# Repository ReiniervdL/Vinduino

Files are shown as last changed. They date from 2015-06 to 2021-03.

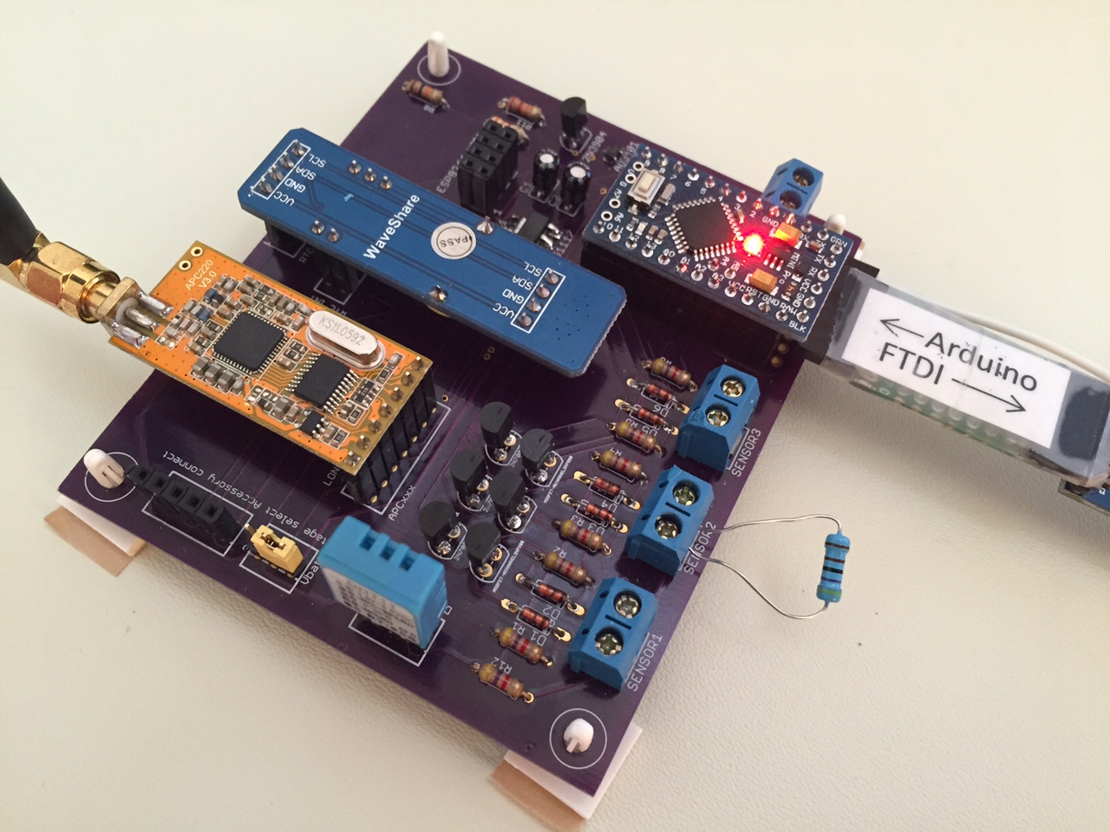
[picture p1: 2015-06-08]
Vinduino-R.JPG

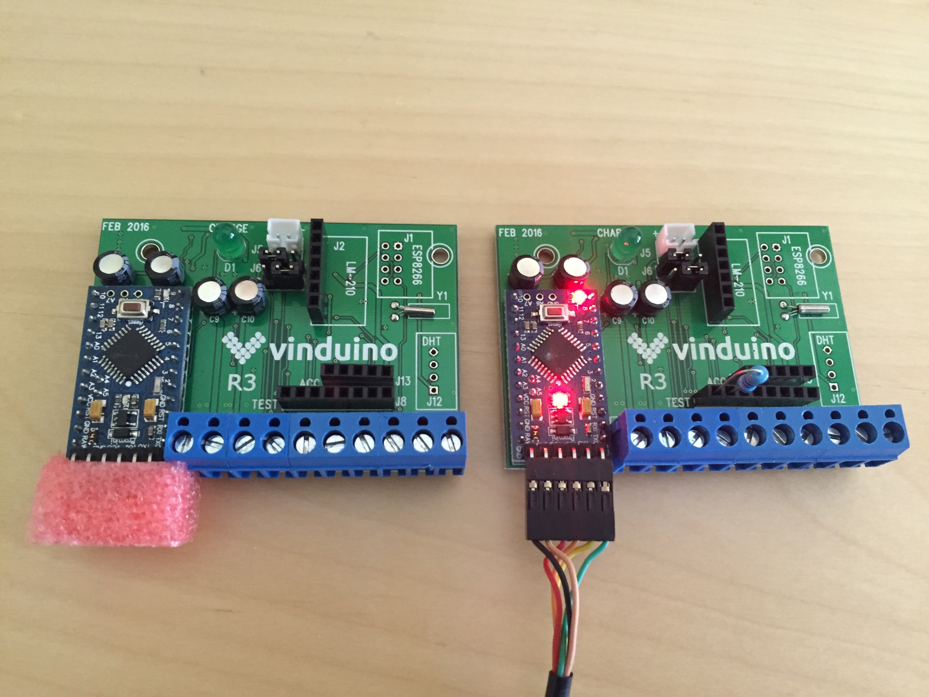
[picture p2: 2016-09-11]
Vinduino-R3/IMG_2257 2.JPG

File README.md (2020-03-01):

# Vinduino

The Vinduino project started from the necessity to manage irrigation in my small Southern California vineyard, by monitoring soil moisture at different depths and at several vineyard locations. 
Soil moisture monitoring systems have been around for decades, but they cost hundreds to thousands of dollars and -because these systems are proprietary- there will be ongoing cost to customize and maintain these systems. As a small vineyard owner, I needed something low cost and flexible.
The open source Arduino platform, together with low cost gypsum soil moisture and salinity sensors, provides all that. While I first envisioned the Vinduino project (Vineyard + Arduino) for my personal interest and needs, but now the scope has broadened to providing easy to use, open source, low cost solutions for agricultural irrigation management.

Saving water is more important now than ever. The four year drought in California made everybody realize the importance of reducing water use. But it is not just California that is plagued by prolonged drought periods. Large agricultural areas in South America, India, China, and Africa suffer from continuing water shortage as well.

The Vinduino project provided the following results, published on the Vinduino blog, Hackaday, and Github:

* DIY calibrated gypsum soil moisture sensors (Watermark SS200 is also supported)
* Hand held sensor reader (soil moisture, soil/water salinity, water pressure)
* Solar powered remote sensor platform (Vinduino R3), available on Tindie.com
	Options include:
	4 electrically separated inputs for soil moisture sensors
	Wifi (ESP8266), Globalsat LM-210 private LoRa network module, Globalsat LM-513 module for LoRaWAN (The Things Network)
	Irrigation valve control, optional pressure sensor for valve operation feedback
	several options for temperature/humidity sensors
	Built in solar battery charger
	Built in real time clock for precise irrigation timing
* Gateway to connect multiple LoRa end nodes to the Internet via Wifi (Vinduino Gateway)

All publicly released programming and documentation is available for free under the GNU General Public License 3.0.

For non-DIY we offer commercial products at www.vinduino.com and https://www.amazon.com/Vinduino-Agricultural-Irrigation-Monitoring-Starter/dp/B0828JCK49

Support web site: https://vinduino.freshdesk.com/support/home

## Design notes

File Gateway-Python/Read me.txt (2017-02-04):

The Vinduino gateway example code for the Globalsat LD20H USB dongle is written in Python3.

Python modules needed for the Vinduino gateway script:
- serial
- time
- thingspeak (linux install: $ sudo pip3 install thingspeak)
- sqlite3

DB browser for SQLite (http://sqlitebrowser.org) is a great program to manage the SQLite database.
Linux install: $ sudo apt-get install sqlitebrowser

For Windows, install the Cypress USB serial driver

For Linux: 
Linux does not require a special drivers for the USB serial interface, however ensure that you have qt4, gcc, and libusb installed.  The USB driver stack in Linux has a built-in driver for CDC-ACM class devices. The Cypress chip inside the LD-20 supports CDC-ACM class, CDC-ACM driver gets automatically bound to the device and creates a device node in /dev/ttyACM*(* -The name of device node will vary based on the number of devices connected).

Here is a good description for testing the USB serial connection in Linux:
http://www.cypress.com/knowledge-base-article/testing-usb-serial-bridge-controller-configured-usb-uart-linux-kba92551

I found that Ubuntu and RPI recognized the USB serial port, but likely assumed it was an AT-command modem. 

A solution that worked for me is to bypass the ModemManager: 

sudo systemctl mask ModemManager.service

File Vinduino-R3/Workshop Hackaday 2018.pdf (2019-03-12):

# Workshop

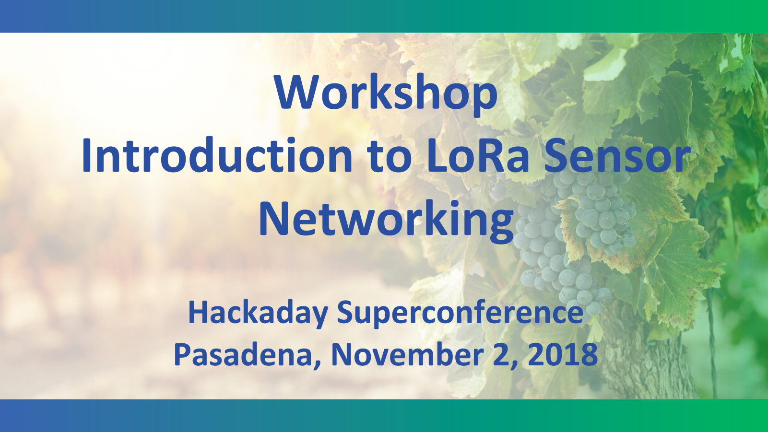
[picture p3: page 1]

# Introduction to LoRa Sensor Networking

# Hackaday Superconference Pasadena, November 2, 2018

# WHAT YOU WILL LEARN

## WHAT IS LORA, AND WHAT MAKES IT DIFFERENT

- Bandwidth, Range, Power
- Network provider: The Things Network

## Globalsat LM-110H1 LoRa module

- Manual setup with serial communication
- Useful AT commands
- Joining a local LoRa network
- Transmit data to an application
- Receive data from an application
- Visualize data in MyDevices Cayenne

# WHAT IS LORA?

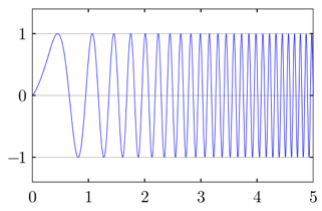
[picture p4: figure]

### Long range, low energy, wireless communication

- Typical 5 mile range with line-of sight
- Suitable for battery operated sensors
- Small data packets, 30 seconds/day air time
~ every 15 - 30 minutes
- Star network topology
- One gateway can support hundreds of stations

### Unlicenced Frequency bands

- USA 902 – 928 MHz, 64 channels
- Europe 863 – 870 MHz, 8 channels

### Modulation

- Chirp spread spectrum, 3 x greater distance than NB FSK
- Data rate depends on bandwidth and spreading factor

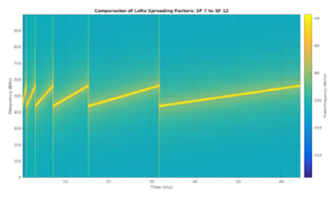
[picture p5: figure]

Sakshama Ghoslya

# LORA NETWORK ARCHITECTURE

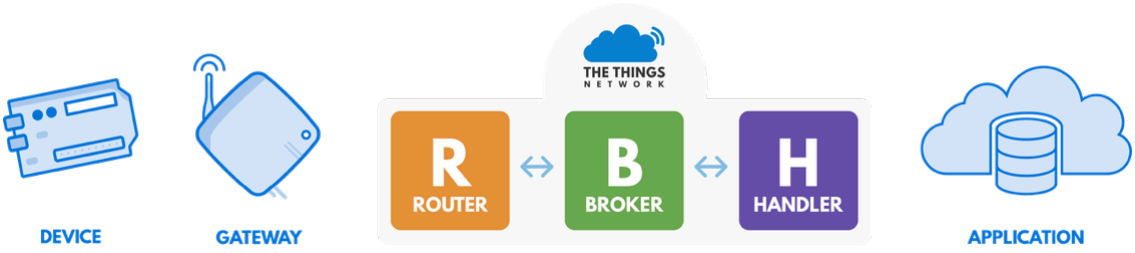
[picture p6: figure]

# LORA NETWORK IN TEMECULA

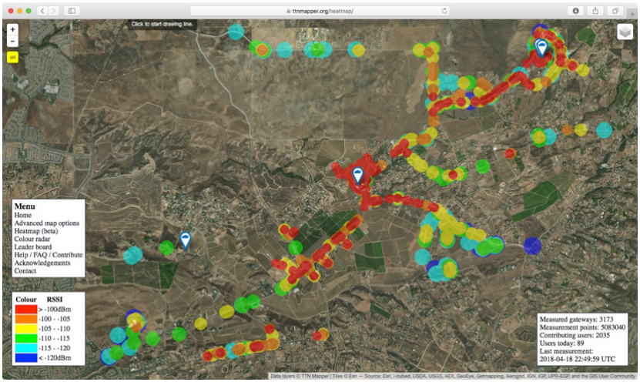
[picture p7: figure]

ttnmapper.org

# WORKSHOP PLAYGROUND

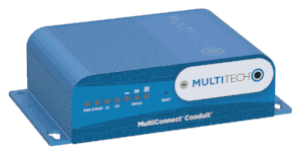
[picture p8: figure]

### LORAWAN GATEWAY

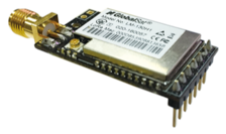
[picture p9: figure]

- MuLtitech Conduit
- Set up for TheThingsNetwork

### LORA NETWORK PROVIDER: TTN

- Free to use LoRaWAN networking
- Community owns and deploys the network
- 5,000 communities worldwide

### YOUR WORKSHOP KIT

- Globalsat LM-110H1 LoRa radio module
- NL100 USB-2-Serial adapter
- 915 MHz Antenna

# GLOBALSAT LM-110H1

LM-110H1 Pin Definition
Pin | Signal Name | I/O | Description
1 | GND | - | Ground
2 | VCC | - | 3.0 – 6.0V
3 | RXD | Input | 3.3V UART input
4 | TXD | Output | 3.3V UART output
5 -7 | - | - | -

Hardware Specifications
Chipset | SEMTECH LoRa SX1276
LoRaWAN Class | Class A device, Receives after Tx
Frequency | 862-870MHz (Model: LM-110E) 902-928MHz (Model: LM-110H)
Transmission Power | 100mW (max.)
UART | Baud Rate : 57600bps Parity: 8N1
Operation Voltage | 3.0V~6V
Current Consumption | Receiving: 21 mA (typical) Transmitting: 125 mA (typical) Sleeping: 5 uA (typical)
Transmission Distance | 1KM~10KM (0.81Kbps)
Receiving Sensitivity | -132dBm@0.81Kbps

# BEFORE WE GET STARTED

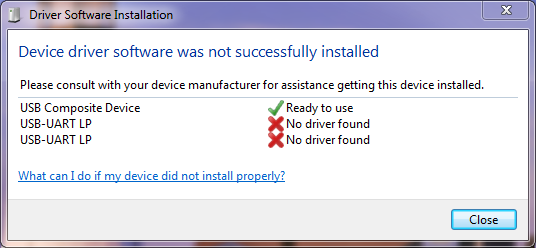
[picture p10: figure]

## WIFI - SSID: | - Pass: |

## WINDOWS USERS

- Install Cypress USB serial driver

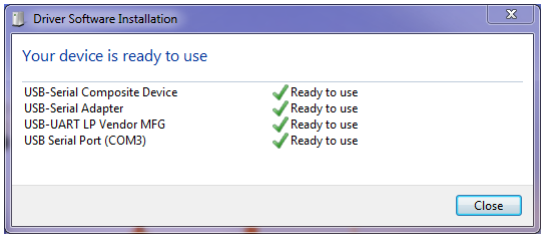
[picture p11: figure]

## Everybody

- Install CoolTerm serial communications program http://freeware.the-meiers.org
- Set up user account at thethingsnetwork.org
- Set up user account at mydevices.com

# BEFORE WE GET STARTED-2

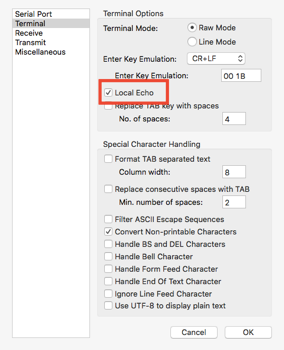
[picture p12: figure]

## CoolTerm Settings

- Select correct serial port
- Baudrate:
57600, 8 bits, no parity, 1 stop bit
- Terminal: Local Echo

## The Things Network

- Set up a user account

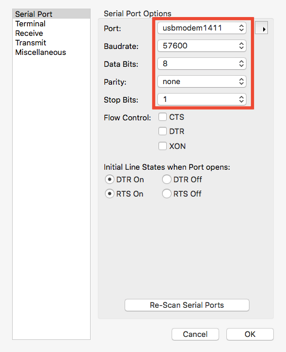
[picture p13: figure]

- https://account.thethingsnetwork.org/register

# AT COMMANDS QUICK REFERENCE

Command | Description | Response
AAT1 Reset | Reboot the LM-110H1 | OK
AAT1 Save | Save parameters to flash | OK
AAT1 SLEEP | Enter sleep mode | OK
AAT2 JoinMode=1 | OTAA activation mode | OK
AAT2 DevEui=? | Device LoRa Mac address | 8-byte hex number
AAT2 AppEui= (enter hex here) | Application identifier | OK
AAT2 AppKey= (enter hex here) | Encryption key | OK
AAT2 Tx=2,uncnf,AABBCC (hex payload) | Send data | OK Tx_ok Tx_noACK Tx_no_free_ch Tx_not_joined Rx …

# MODULE MANUAL CONFIGURATION

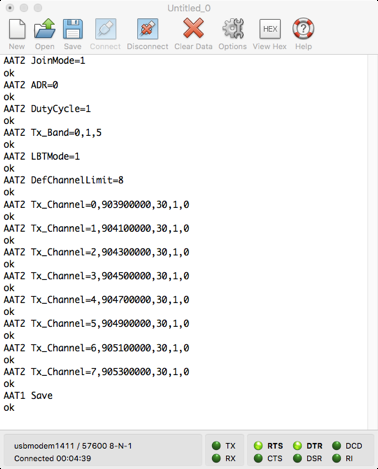
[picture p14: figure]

AAT2 JoinMode=1
AAT2 ADR=0
AAT2 DutyCycle=1
AAT2 Tx_Band=0,1,5
AAT2 LBTMode=1
AAT2 DefChannelLimit=8

AAT2 Tx_Channel=0,903900000,30,1,0 AAT2 Tx_Channel=1,904100000,30,1,0 AAT2 Tx_Channel=2,904300000,30,1,0 AAT2 Tx_Channel=3,904500000,30,1,0 AAT2 Tx_Channel=4,904700000,30,1,0 AAT2 Tx_Channel=5,904900000,30,1,0 AAT2 Tx_Channel=6,905100000,30,1,0 AAT2 Tx_Channel=7,905300000,30,1,0 AAT1 Save

Same for every
module setup

Frequencies can differ
per network provider

# TTN ADD APPLICATION

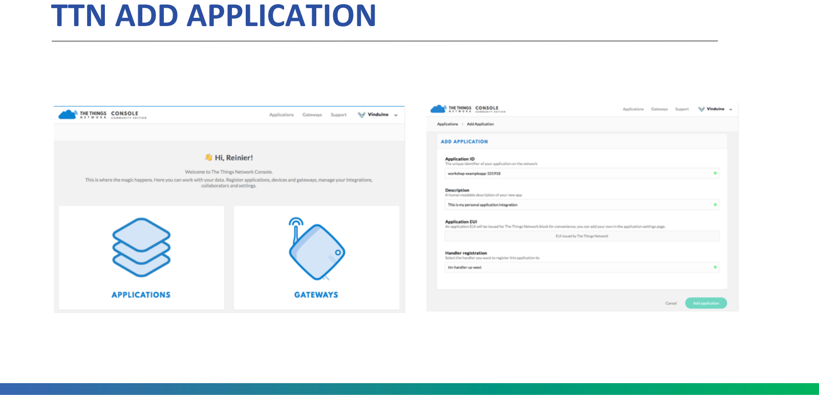
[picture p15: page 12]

# MODULE MANUAL CONFIGURATION-2

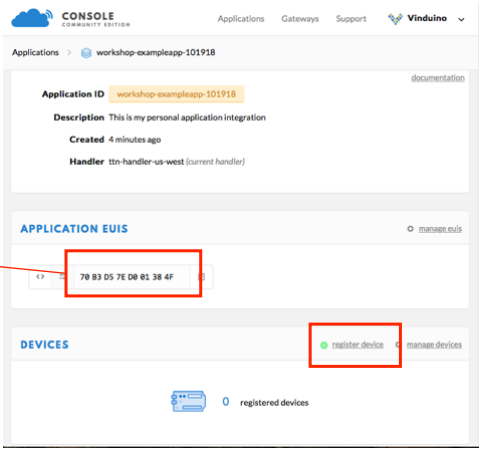
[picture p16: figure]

AAT2 DevEui=?
000DB53908643681
(should be the same as module marking)

AAT2 AppEui=70B3D57ED001384F AAT1 Save

AAT2 AppKey=
AAT1 Save
AAT1 Reset

Save DevEUI for
TTN registration

# TTN REGISTER DEVICE

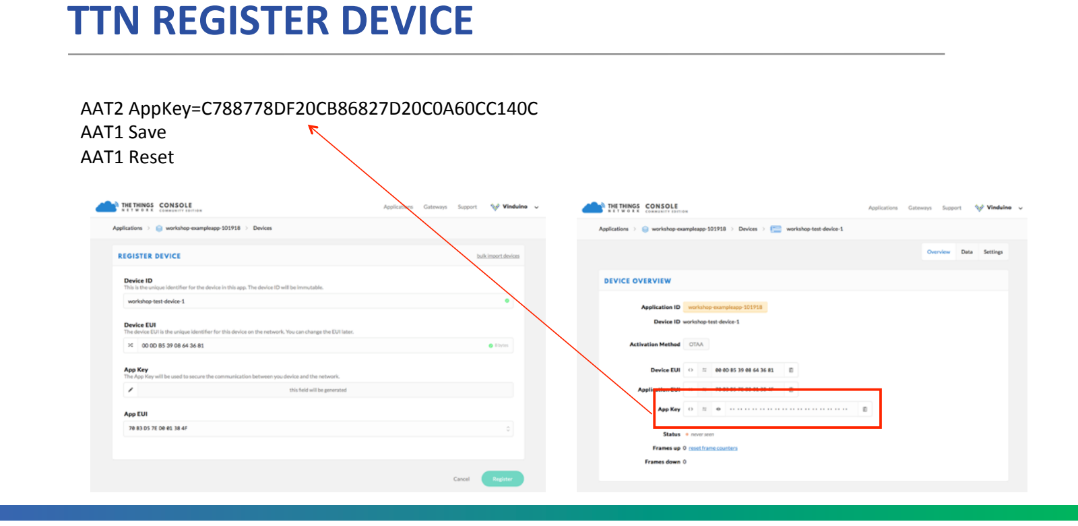
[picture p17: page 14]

AAT2 AppKey=C788778DF20CB86827D20C0A60CC140C AAT1 Save
AAT1 Reset

# CONNECTED TO THE LORA NETWORK!!

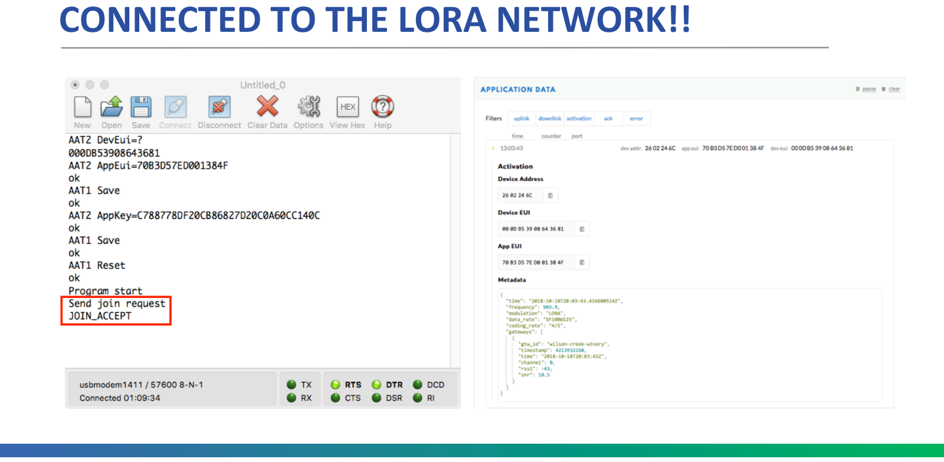
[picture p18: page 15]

# NOW LET’S SEND SOME DATA!!

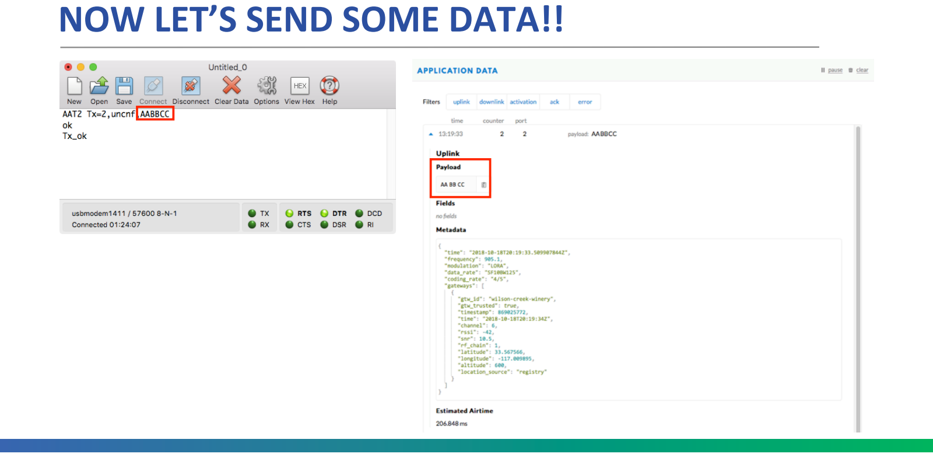
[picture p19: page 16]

# RECEIVING DATA

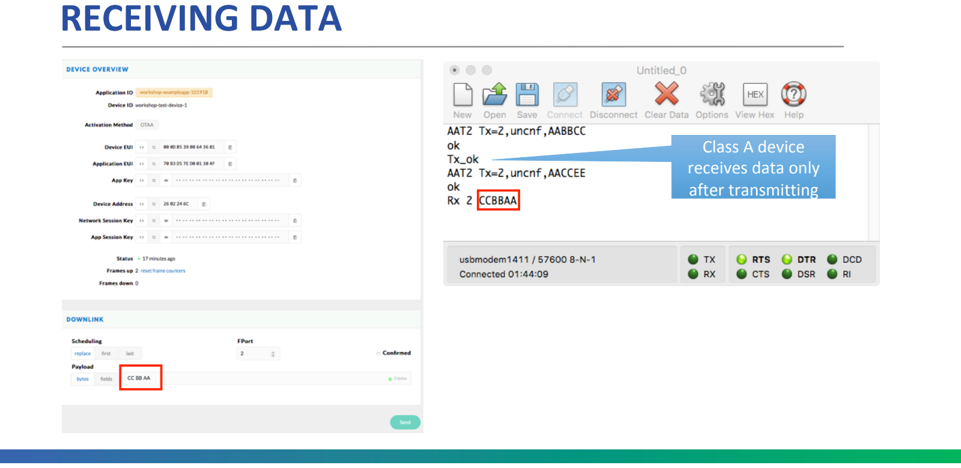
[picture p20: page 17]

Class A device
receives data only
after transmitting

# VISUALIZE YOUR SENSOR DATA

## ADD CAYENNE INTEGRATION

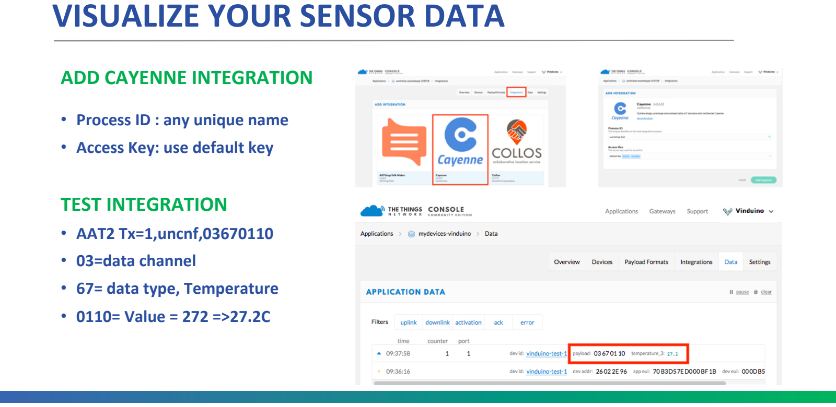
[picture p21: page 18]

- Process ID : any unique name
- Access Key: use default key

## TEST INTEGRATION

- AAT2 Tx=1,uncnf,03670110
- 03=data channel
- 67= data type, Temperature
- 0110= Value = 272 =>27.2C

# USING CAYENNE

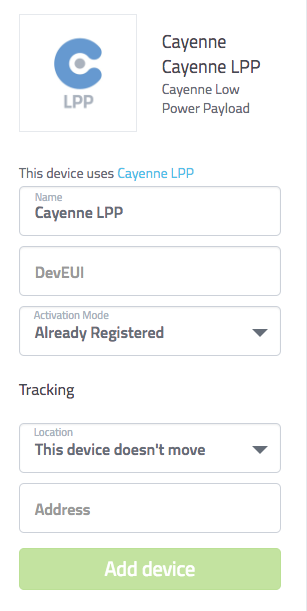
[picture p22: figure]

## SET UP DEVICE IN CAYENNE

- Add new … Devices & Widgets
- Select LoRa / TheThingsNetwork
- In devices list: select Cayenne LPP
- Enter DevEUI:
- AAT2 Tx=1,uncnf,03670110

# CONGRATULATIONS

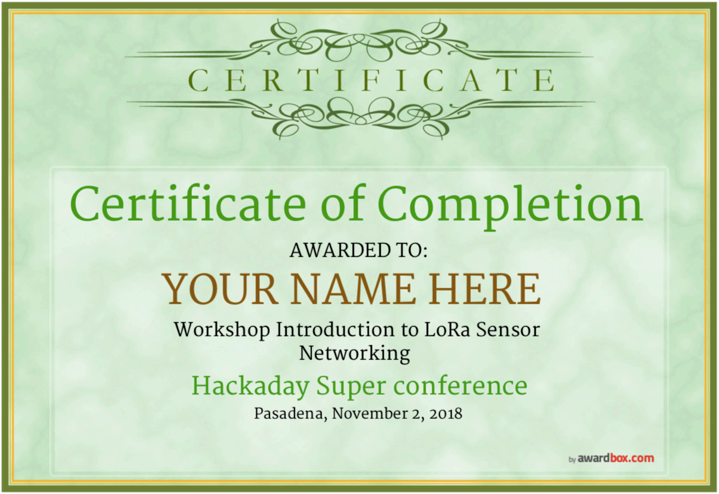
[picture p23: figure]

# USEFUL LINKS

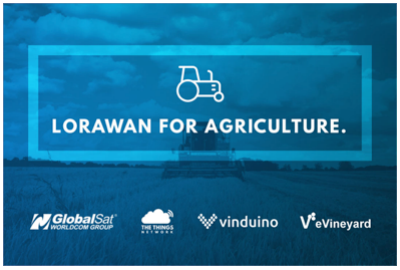
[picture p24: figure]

www.thethingsnetwork.org/community/losangeles/ https://www.thethingsnetwork.org www.usglobalsat.com
www.vinduino.com
www.tindie.com
lora-alliance.org

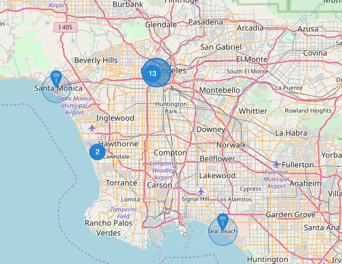
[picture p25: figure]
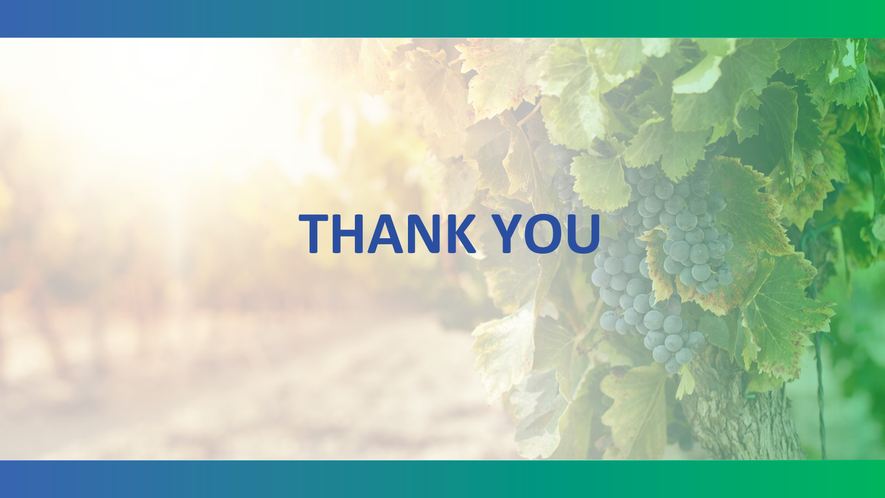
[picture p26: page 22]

# THANK YOU

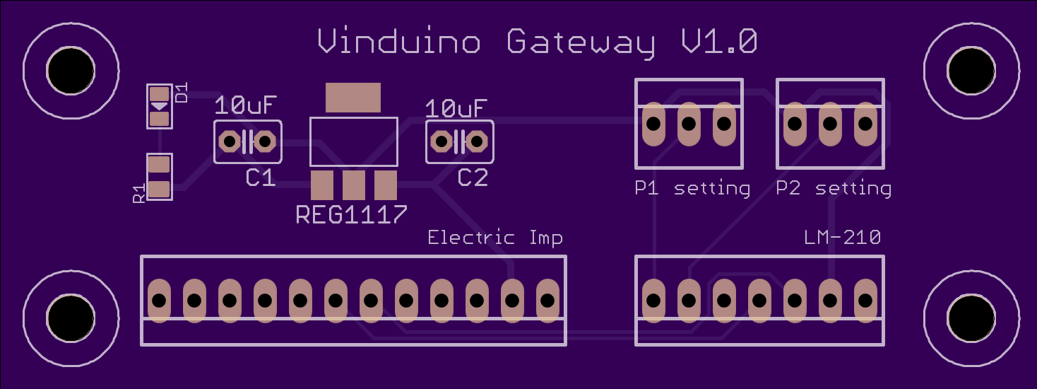
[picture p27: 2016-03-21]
Vinduino-Imp-GW-PCB/Vinduino-GW.png

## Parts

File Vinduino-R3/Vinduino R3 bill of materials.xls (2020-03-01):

Part/Designator | Manufacture Part Number | Quantity | Hole Pads | Ext hole pads | Ext SMD pads | Description | Comments
U4 | 74HC4052D,653 | 1 | 16 |  | 16 | IC MUX/DEMUX DUAL 4X1 16SOIC
R14, R15, R8 | RC0805FR-07100KL | 3 | 2 |  | 6 | RES SMD 100K OHM 1% 1/8W 0805
R9, R10 | RR1220P-4751-D-M | 2 | 2 |  | 4 | RES SMD 4.75KOHM 0.5% 1/10W 0805
R1, R2,R3, R6, R7, | RMCF0805JT4K70 | 5 | 2 |  | 10 | RES SMD 4.7K OHM 5% 1/8W 0805
R5 | RC0805JR-0710KL | 1 | 2 |  | 2 | RES SMD 10K OHM 5% 1/8W 0805
C1, C4, C5, C6, C7, C8 | CC0805ZRY5V9BB104 | 6 | 2 | 12 |  | CAP CER 0.1UF 50V Y5V 0805
F1 | RXEF025-2 | 1 | 2 | 2 |  | POLYSWITCH RXE SERIES 0.25A | SMD type preferred
C2 | C0603C100J5GACTU | 1 | 2 |  | 2 | CAP CER 10PF 50V NP0 0603
U3 | PCF8563T/5,518 | 1 | 8 |  | 8 | IC RTC CLK/CALENDAR I2C 8-SOIC
Y1 | ECS-.327-8-14X | 1 | 2 | 2 |  | CRYSTAL 32.7680KHZ 8PF T/H
J4 | OSTTA020161 | 5 | 2 | 10 |  | TERMINAL BLOCK 5MM VERT 10 POS PCB | use 5x 2 terminal or 1 x 10 pos terminal block
U2 | MCP73831T-2ACI/OT | 1 | 5 |  | 5 | IC CONTROLLR LI-ION 4.2V SOT23-5
D1 | LTST-C171GKT | 1 | 2 | 2 |  | LED GREEN CLEAR 0805 SMD | or through hole LED
R4 | RC0805JR-07470RL | 1 | 2 |  | 2 | RES SMD 470 OHM 5% 1/8W 0805
J13 | PPTC051LFBN-RC | 1 | 5 | 5 |  | CONN HEADER FEM 5POS .1" SGL TIN
J2 | PPPC071LFBN-RC | 1 | 7 | 7 |  | CONN HEADER FEMALE 7POS .1" GOLD
J3, J6 | 68000-103HLF | 2 | 3 | 6 |  | BERGSTIK II .100" SR STRAIGHT
J3, J6 | 969102-0000-DA | 2 |  |  | 0 | SHUNT JUMPER .1" BLACK GOLD
U6 | MCP1825S-3302E/DB | 1 | 4 |  | 4 | IC REG LDO 3.3V 0.5A SOT223-3
U5 | SI1869DH-T1-E3 | 1 | 6 |  | 6 | IC LOAD SW LVL SHIFT 20V SC70-6
D2, D3, D4, D5 | MMBZ9V1ALT1G | 4 | 3 |  | 12 | Dual TVS protection diode
C9, C10, C11, C12 | ECE-A1AKS470 | 4 | 2 | 8 |  | CAP Alum 47UF 20% 10V Radial | value not critical
J5 | B2B-PH-K-S(LF)(SN) | 1 | 2 | 2 |  | JST-PH 2-Pin SMT 2 Positions Header, Shrouded Connector 0.079" (2.00mm) | non-angle connector (vertical insertion) preferred
Arduino Pro Mini 3.3V 8MHz |  | 1 | 58 | 58

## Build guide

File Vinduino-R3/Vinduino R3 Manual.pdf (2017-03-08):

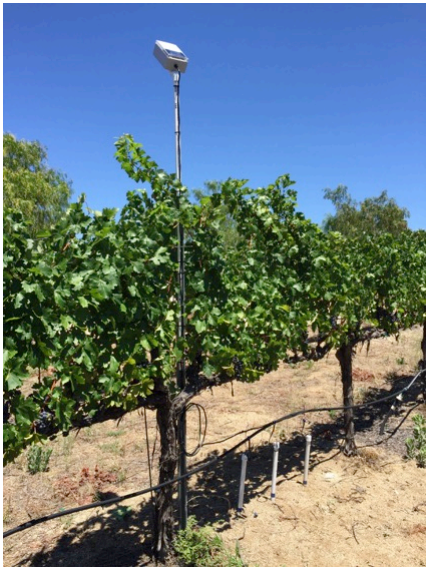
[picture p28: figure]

## Vinduino User Manual

Draft version July 30,2016 Updated August 4, 2016

Table of contents

## Introduction

Vinduino remote sensor platform for optimizing agricultural irrigation

The Vinduino R3 sensor station contains all the electronics needed for a solar powered remote sensor platform. It is designed for optimizing agricultural irrigation, aimed at saving 25% irrigation water. This board represents the 3rd generation design of our remote sensor platform, and has gone through extensive vineyard field trials.

Features:
- Arduino based, easy to customize programming
- 4 electrically separated inputs for soil moisture sensors
- Supports Wifi (ESP8266, not included) or Globalsat LM-210 LoRa module for long range
- Irrigation valve control output
- Several options for temperature/humidity sensors
- Solar battery charger
- Real time clock for sleep mode power saving and precise irrigation timing
- Load switch for actuators or sensors that require electric power

Supported sensors:
- Vinduino soil moisture sensor
- Watermark SS200 soil moisture sensor
- DHT11, DHT22
- DS18b20

The Vinduino board is designed for continuous unattended operation. It can be powered by a small solar panel, and the battery charger maintains a Li-ion battery fully charged, to keep the system working during the night and during periods with dense cloud cover. The battery voltage can be monitored remotely to check battery health.

The LM-210 module requires a compatible gateway, and is designed for LoRa LAN.

## Scope

This user manual covers use and installation of the Vinduino R3 remote sensor station and the Vinduino Gateway

## Disclaimer

Always use multiple data sources, appearance of your crop, and common sense when making irrigation decisions. Vinduino LLC is not responsible for crop yield results.

## Sensors

The Vinduino R3 is designed to support up to 4 resistive soil moisture sensors. These can be gypsum sensors, like the Vinduino sensor shown below, or commercial sensors like the Watermark SS200 granular matrix sensor.

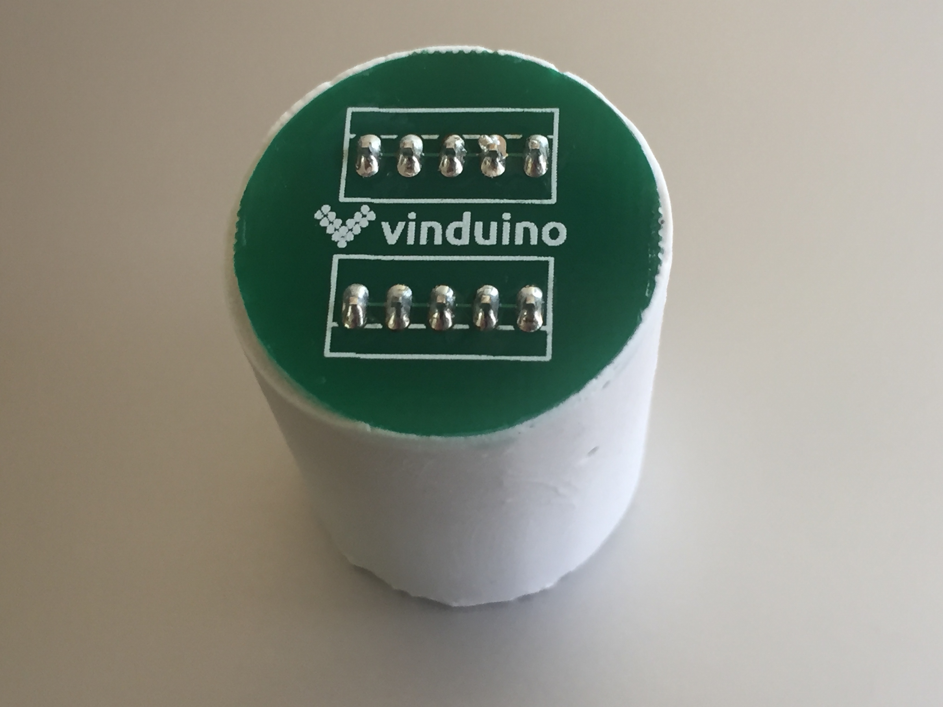
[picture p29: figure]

The Vinduino design uses short alternating electrical pulses to measure the resistance of the sensor, which is a measure of the water content of the soil. A low resistance indicates high moisture, whereas a high resistance value indicates low water availability. The resistance is expressed in Ohm, and can be used in combination with a calibration chart to determine water content.

Vinduino calibration chart to be inserted here at next document update

For Watermark SS200 sensors, calibration is well documented (Shock et all) and available on-line:
http://www.kimberly.uidaho.edu/water/swm/Calibration_Watermark2.htm

The Vinduino remote sensor station has the option to support other types of sensors. Here is a list of sensors that have been tested to work with the Vinduino:

DHT11 air temperature and humidity sensor, temperature accuracy 2%, RH accuracy 5%

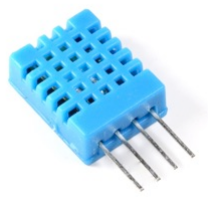
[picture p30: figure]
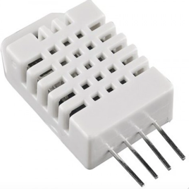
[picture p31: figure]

DHT22 air temperature and relative air humidity sensor temperature accuracy 0.5%, RH accuracy 2%

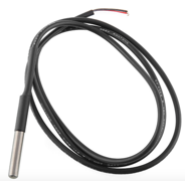
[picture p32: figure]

DS18b20 waterproof 0.5% accurate digital temperature sensor 3 wire interface (Red =Vcc, Black =ground, Yellow=data out)

The choice of sensors needs to be agreed when ordering, as the Vinduino R3 programming and Internet interface needs to be configured to support the selected sensors. Sensors can be added later, and the supporting software can be upgraded in the field.

Sensor installation
The installation of sensors needs preferably be done at least two weeks before the anticipated activation of the remote sensor station.
The Vinduino project uses 4 soil moisture sensors at different depths per location to determine the percolation of irrigation water in the soil.
For wine grapes, the recommended installation depths are 1 foot, 2 feet, 4 feet, and 5 feet.
The sensor at 5 feet is to be considered below the active root zone, and should show low moisture levels as drainage of irrigation water below 4 feet is out of reach of the grapes.

Ideally, all sensors should be vertically aligned close to an irrigation dripper.
For easy maintenance and replacement, 1“ PVC pipe is recommended to mount and install the sensor at the desired depth. Keeping 1’ of pipe above ground helps avoid wildlife damage to the electrical wiring.

TIP:
For Vinduino sensors, PVC pipe can be widened after applying hot air with a heat gun. After inserting the sensor, re-heating with shrink the pipe to tightly fit around the sensor.

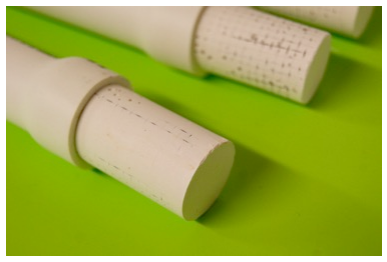
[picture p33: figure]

Gypsum sensors need a good soak before installation in the soil. To ensure good soil contact, put some soil slurry in the hole and make sure that the sensor is well settled into the slurry before filling up with soil.
Link to sensor installation guidelines: http://mea.com.au/upload/new/product_brochures/b83_soil-moisture_sensor_installation_guide_web.pdf

## Vinduino R3, remote sensor station

Solar power
The remote sensor station is designed for continuous unattended operation. It is powered by a small solar panel, and the battery charger keeps the battery fully charged to keep the system working during the night and during periods with dense cloud cover. A green LED on the electronics board indicates that the charger is operational.
The battery voltage is measured and sent together with the sensor data. A healthy battery should provide a voltage between 4.2V and 3.6V. Below 3.6V, the battery is close to empty.

The battery connector is also used to switch the system on or off. Disconnect the solar panel before disconnecting the battery to avoid the system continuing on solar power.

Important: the solar panel is connected to the wire terminal block. The red wire connects to the “+”, and the black wire connects to the “-“. Connecting the solar panel with the wires with reversed polarity will damage the battery charging chip.

Connecting sensors
The Vinduino R3 has inputs for 4 soil sensors. The soil sensor wires connect to the wire connection block. Sensor 1 wires are connected on the right side. The type of wiring is not critical for the accuracy or performance of the soil moisture measurement.

The printed circuit board is designed to support a DHT11 or DHT22 sensor (temperature and relative humidity). These sensors are not waterproof and can only be used for measuring inside the enclosure.
For temperature measurement outside the enclosure, soil or air temperature, a waterproof temperature sensor like the DS18b20 can be used.

Other sensors can be attached using the “Accessories” connector on the electronics board. This connector gives access to 2 digital pins, an analog input, and a switched 3.3V power supply pin that can be used for sensors that require electric power. Future use of the accessories connector is to control an irrigation valve and water pressure sensor.

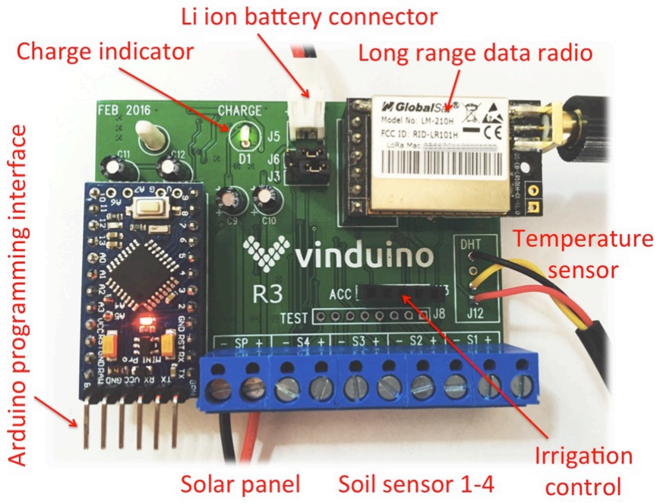
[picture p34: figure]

Timer
The Vinduino R3 has an integrated clock chip that is used to wake up the system from power saving sleep mode. After the Vinduino is done with making measurements and transmitted the measurement data, it goes back to sleep again.
During the active mode, a LED on the Arduino board lights up.
Typically, the timer is programmed for 15 minutes or one hour. When many remote sensor stations share one gateway, it is better to have longer interval times to avoid “crowding” of the radio frequency.

The timer can also be used (future) for precision irrigation timing, or keeping system time.

LM-210 radio module
The telemetry radio unit used in the Vinduino project follows the recent LoRa standard, which allows long range wireless networking. The unit is FCC approved in the USA for license-free use in the 915 MHz band.
Range is dependent on the conditions. With the supplied antennas typically 1-3 miles is possible. With line-of-sight and external antennas, considerable longer distances are possible.

The unit can be re-programmed for different output power levels and frequency. The default settings are 915 MHz and 100mW power. Frequency change is only needed in vase of strong local interference from other users of the frequency or in case of installation in Europe where 868MHz is used for LoRa.

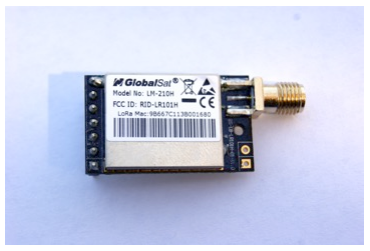
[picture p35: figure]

The Vinduino sensor station is designed for supporting the LM-210. Before programming the Arduino microcontroller board with a USB adapter cable, the LM-210 module should be removed to avoid USB level voltages (5V) reaching the module.

Programming
In order to change the program code of the Vinduino, for instance to change the wake up time or change sensors, you will need a programming cable and Arduino PC software. The USB programming cable is needed to connect to a PC
Please use the 3.3V version of the cable: http://amzn.com/B00DJBPIGI

The radio module needs to be removed before programming and connecting the programming cable.

Arduino programming software is available for free for most recent computer operating systems: https://www.arduino.cc/en/Main/Software

Vinduino programming code is available for download via Github: https://github.com/ReiniervdL/Vinduino

Vinduino R3 installation and maintenance
The remote sensor station comes as a watertight NEMA enclosure. Sensor cables should enter the enclosure using a NEMA rated cable gland (supplied).
The unit can be mounted at an angle for the solar panel to get best exposure to the available sunlight. Best direction for the solar panel is facing South.

TIP: It is recommended to spray paint the transparent cover partially white to keep the temperature inside the enclosure lower. Leave the solar panel area clear.
This will improve the life of your battery.

Due to exposure to sunlight, the battery will be operating at high operating temperatures. It is therefore recommended to frequently check the battery for visible mechanical deformation, in which case replacement is needed. Annual replacement of the battery is recommended preventive maintenance for outdoors installations where the unit is in continuous operation.

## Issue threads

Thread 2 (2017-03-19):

LowPower.h source

Elwell, 2017-03-19:
Hi Reinier,

In the arduino sketches, you #include "LowPower.h" that isn't in the tree.

Is this from https://github.com/rocketscream/Low-Power, described in http://www.rocketscream.com/blog/2011/07/04/lightweight-low-power-arduino-library/ ?

ReiniervdL, 2017-03-19:
Hi Andy,
Correct, Vinduino uses the rocketscream low power library

Closed 2017-03-19.

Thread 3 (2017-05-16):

Negative values of resistance, Soil moisture always zero!

aniket5941, 2017-05-16:
I'm using Vinduino-H_V3.1 code, soil moisture always shows **zero** for **WET** and **DRY** and resistance is always **NEGATIVE** I done connection according picture attached, but I'm using **4700 ohm resistance** help me what I'm doing wrong, I have attached images of connection and readings, first reading image is of wet and second is for dry.
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

ReiniervdL, 2017-05-16:
The code for the handheld was written for Arduino Pro Mini pin assignments.
What model of Arduino are you using?

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

aniket5941, 2017-05-17:
Arduino pro mini 3.3v model

ReiniervdL, 2017-05-17:
First question, do you have test equipment: multimeter, oscilloscope?

The code was written for the 5V version of the Arduino pro mini.
For 3.3V, I recommend removing the diodes, as they take away 0.6V from the voltage divider supply.
Next you need to program the outputs to high impedance when not used as output.
You can copy the code from the Vinduino R3 on Github for this.

Last but not least, double check your wiring.

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

aniket5941, 2017-05-18:
No I'm not using any test equipment: multimeter, oscilloscope.
I tried Vinduino R3 on **Arduino UNO** but the same problem occurs.

ReiniervdL, 2017-05-22:
I'd like to help with debugging if you provide me basic measurement data.  A $10 digital multimeter will go a long way get getting insight in what's going on. If you want to skip fault finding,  use the PCB design for the handheld reader, available here:
https://oshpark.com/shared_projects/QWzdU5S6

aniket5941, 2017-05-23:
Thank you very much ,
I have DMM and my is circuit on bread board, I'm in little hurry so pcb would take time, so how should I proceed what data would you like to have from me.

ReiniervdL, 2017-05-23:
Can you first check the power supply voltage?
Next, can you modify the “Blink” example program (in the Arduino IDE) to check that the two outputs driving the diodes are toggling.
Make the delay long, so your DMM can track the changing states.

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

warriorfenixSM, 2018-05-14:
This values is with 22k in WM1:

WM1: 298552,2
WM1: 8670,15
WM1: 201160,2
WM1: 8706,15
WM1: 297079,2
WM1: 8409,15
WM1: 284256,2
WM1: 7925,15
WM1: 291596,2
WM1: 8521,15
WM1: 322377,2
WM1: 7823,15
WM1: 183822,2

Closed 2020-03-01.

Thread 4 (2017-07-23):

USB serial crash using ftdi

pandrews255, 2017-07-23:
I'm using the Vinduino R3 with the 2nd LM-210 wired into the Raspberry Pi.  After a random amount of time (minutes but rairly to hours) the USB serial crashes out and forces a reboot/re-plug of the usb ftdi in order to work again.  Easiest way to see this error is through:

`dmesg -T`
with the result:
`Nov 4 14:23:13 localhost kernel: [11761.350820] ftdi_sio ttyUSB0: usb_serial_generic_read_bulk_callback - urb stopped: -32 `
(Note: this was not my exact error, but was close enough and how I found my solution.)

Solution:[https://github.com/raspberrypi/linux/issues/1187](url)

> You could try the nuclear option - add dwc_otg.speed=1 to /boot/cmdline.txt - this forces the entire bus to USB1.1 speeds. If you still get disconnects after that, then it's probably safe to say that the Pi isn't the issue.

This fixed my issue, though it seems a bit inelegant.  I don't need any high speed USB devices on the pi, so it seems effective.

No real question here, just posting for posterity.  Perhaps best in a Wiki format, but didn't see any other wiki pages.  If a more elegant solution exists, I'd be willing to try it.

ReiniervdL, 2017-07-25:
Thanks!!
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

Closed 2017-08-06.

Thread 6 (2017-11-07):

Bill of Materials for Vinduino R3

Bigben83, 2017-11-07:
I cant seem to see a BOM list for the parts used on the R3
can you point me in the right direction please :-)

Bigben83, 2017-11-07:
I have done a list up from the Schematic, there is a few holes to fill though.
https://docs.google.com/spreadsheets/d/1UatllHvDW_FJPWLYLjqeTI9wG5EkYtphUCcHgDXFkBM/edit?usp=sharing

Bigben83, 2018-12-10:
Hello @ReiniervdL can you please tell me what the Diodes are D2-D5  are they a "9A1" 9.1V 0.3W zener?

DanChippps, 2020-02-27:
Hi @Bigben83, Did you manage to figure this question out?

Bigben83, 2020-03-01:
Hi @DanChippps no I didn't, I gather this is no longer maintained opensource hardware/software.
I have built several of these units. I will have a look and see what I actually used.

ReiniervdL, 2020-03-01:
The BOM has been added

Closed 2020-03-01.

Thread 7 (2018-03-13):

Soil Moisutre Measure not works!

warriorfenixSM, 2018-03-13:
Hi, i try works your source code: Vinduino-H_V3.1.ino with only one watermark connect to Arduino M0. But it doesn't work. I see the signal in the oscilloscope, but the code no changes values

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

And this mi code:

#include <math.h>

#define NUM_READS 11    // Number of sensor reads for filtering

typedef struct {        // Structure to be used in percentage and resistance values matrix to be filtered (have to be in pairs)
  int moisture;
  long resistance;
  double tension;
} values;

const long knownResistor = 4700;  // Constant value of known resistor in Ohms

int activeDigitalPin = 11;         // 6 or 7 interchangeably
int supplyVoltageAnalogPin;       // 6-ON: A0, 7-ON: A1
int sensorVoltageAnalogPin;       // 6-ON: A1, 7-ON: A0

int supplyVoltage;                // Measured supply voltage
int sensorVoltage;                // Measured sensor voltage

values valueOf[NUM_READS];        // Calculated moisture percentages and resistances to be sorted and filtered

int i;                            // Simple index variable

void setup() {
  // initialize serial communications at 9600 bps:

  SerialUSB.begin(9600);
analogReadResolution(12);
  // initialize the digital pin as an output.
  // Pin 6 is sense resistor voltage supply 1
  pinMode(11, OUTPUT);

  // initialize the digital pin as an output.
  // Pin 7 is sense resistor voltage supply 2
  pinMode(13, OUTPUT);
}

void loop() {

      bemoticCore.ON_SENS();
  for (i=0; i<NUM_READS; i++) {

    setupCurrentPath();      // Prepare the digital and analog pin values

    // Read 1 pair of voltage values
    digitalWrite(activeDigitalPin, HIGH);                 // set the voltage supply on
    delay(10);
    supplyVoltage = analogRead(supplyVoltageAnalogPin);   // read the supply voltage
    SerialUSB.print("SV:");
    SerialUSB.println(supplyVoltage);
    sensorVoltage = analogRead(sensorVoltageAnalogPin);   // read the sensor voltage
    SerialUSB.print("SV:");
    SerialUSB.println(sensorVoltage);
    digitalWrite(activeDigitalPin, LOW);                  // set the voltage supply off
    delay(10);

    // Calculate resistance and moisture percentage without overshooting 100
    // the 0.5 add-term is used to round to the nearest integer
    // Tip: no need to transform 0-1023 voltage value to 0-5 range, due to following fraction
    valueOf[i].resistance = long( float(knownResistor) * ( supplyVoltage - sensorVoltage ) / sensorVoltage + 0.5 );
    valueOf[i].moisture = min( int( pow( valueOf[i].resistance/31.65 , 1.0/-1.695 ) * 400 + 0.5 ) , 100 );
//    valueOf[i].tension = round( -20 * (double(valueOf[i].resistance)/1000) * ( 1 - 0.55)); // Watermark 0 < 1 kOhm
    valueOf[i].tension = round( ( -3.213 * (double(valueOf[i].resistance)/1000) - 4.093) / ( 1 - 0.009733 * (double(valueOf[i].resistance)/1000) - 0.01205*24)); // Watermark 1 < 8 kOhm
//    valueOf[i].tension = round(-2.246 - (5.239 * (double(valueOf[i].resistance)/1000)) - 0.06756 * pow(valueOf[i].resistance/1000,2)); // Watermark > 8 kOhm
//  valueOf[i].moisture = min( int( pow( valueOf[i].resistance/331.55 , 1.0/-1.695 ) * 100 + 0.5 ) , 100 );

  }
      sortMoistures();
 
      // Print out median values
      SerialUSB.print("SV: ");
      SerialUSB.println(supplyVoltage);
      SerialUSB.print("Se: ");
      SerialUSB.println(sensorVoltage);
      SerialUSB.print("Resistencia Sensor: ");
      SerialUSB.println(valueOf[NUM_READS/2].resistance);
      SerialUSB.print("Moisture Sensor: ");
      SerialUSB.println(valueOf[NUM_READS/2].moisture);
      SerialUSB.print("Tension Sensor: ");
      SerialUSB.print(valueOf[NUM_READS/2].tension);
      SerialUSB.println(" kPa");
      delay(3000);

}

void setupCurrentPath() {
  if ( activeDigitalPin == 11 ) {
    activeDigitalPin = 13;
    supplyVoltageAnalogPin = A2;
    sensorVoltageAnalogPin = A0;
  }
  else {
    activeDigitalPin = 11;
    supplyVoltageAnalogPin = A0;
    sensorVoltageAnalogPin = A2;
  }
}

// Selection sort algorithm
void sortMoistures() {
  int j;
  values temp;
  for(i=0; i<NUM_READS-1; i++)
    for(j=i+1; j<NUM_READS; j++)
      if ( valueOf[i].moisture > valueOf[j].moisture ) {
        temp = valueOf[i];
        valueOf[i] = valueOf[j];
        valueOf[j] = temp;
      }
}

ReiniervdL, 2018-03-13:
The Vinduino-H code is for a handheld reader, works for one sensor only.

Can you describe your setup?
Are you using the Vinduino handheld PCB?
Does the code compile?

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

warriorfenixSM, 2018-03-13:
I try to use the Vinduino handheld PCB and i have connect only sensors. I try use your code in a samd21 board
But the measures not's works

ReiniervdL, 2018-03-13:
I have no experience with the SAMD21 board.
The operating principle is measuring a voltage in a voltage divider, where one of the resistors is the sensor, and the other resistor is your reference.
You should check correct wiring first and then look at the ADC measurements. Also make sure that the Watermark sensor is wetted, a dry sensor is infinite impedance.

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

ReiniervdL, 2018-05-14:
A dry watermark sensor is basically an open circuit.
You may want to check your circuit first with known resistor values connected to the sensor inputs.

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

warriorfenixSM, 2018-05-14:
This values is with 22k in WM1:

WM1: 298552,2
WM1: 8670,15
WM1: 201160,2
WM1: 8706,15
WM1: 297079,2
WM1: 8409,15
WM1: 284256,2
WM1: 7925,15
WM1: 291596,2
WM1: 8521,15
WM1: 322377,2
WM1: 7823,15
WM1: 183822,2

Part of Code:

SerialUSB.print("WM1: ");
SerialUSB.print(valueOf[NUM_READS/2].resistance);
SerialUSB.print(",");
SerialUSB.print(valueOf[NUM_READS/2].moisture);
SerialUSB.println ();

Thanks so much!

ReiniervdL, 2018-05-14:
The SerialUSB.print(valueOf[NUM_READS/2].resistance should show a value of 22k.
I cannot tell you remotely why it does not work.

First thing to try is program the unit to provide static state DC to the interface voltage divider.
Use a volt meter to measure the voltage and compare with the ADC input reading.

Best,

-Reinier-

> On May 14, 2018, at 2:03 PM, warriorfenixSM <notifications@github.com> wrote:
>
> SerialUSB.print(valueOf[NUM_READS/2].resistance

warriorfenixSM, 2018-05-15:
Hi, i fix now the board, the problem is in my pcb.

Thanks for you support!

Closed 2018-05-15.

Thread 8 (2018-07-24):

Missing library

ShinyEdu, 2018-07-24:
Sample code inludes a library LowPower.h but I can't find any libraries that match that name.

```
H:\Outbox\Vinduino-20180719T042419Z-001\Vinduino\Vinduino-R3_Wifi\VR3-WiFi-sample_code\Vinduino-R_Wifi_V1.0.ino:20:49: fatal error: LowPower.h: No such file or directory

 #include "LowPower.h"   // Needed for sleep mode

                                                 ^

compilation terminated.

exit status 1
Error compiling for board Arduino Pro or Pro Mini.
```

ShinyEdu, 2018-07-26:
There are many other libraries missing, do you have a list of all additional libraries required?

ReiniervdL, 2020-03-01:
The list of the libraries is in the code. You can easily find them if you Google....

Closed 2020-03-01.

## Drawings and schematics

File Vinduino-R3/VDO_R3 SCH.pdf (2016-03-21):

## ESP8266 MODULE

ARDUINO PRO MINI 3V3 | SENSOR MUX

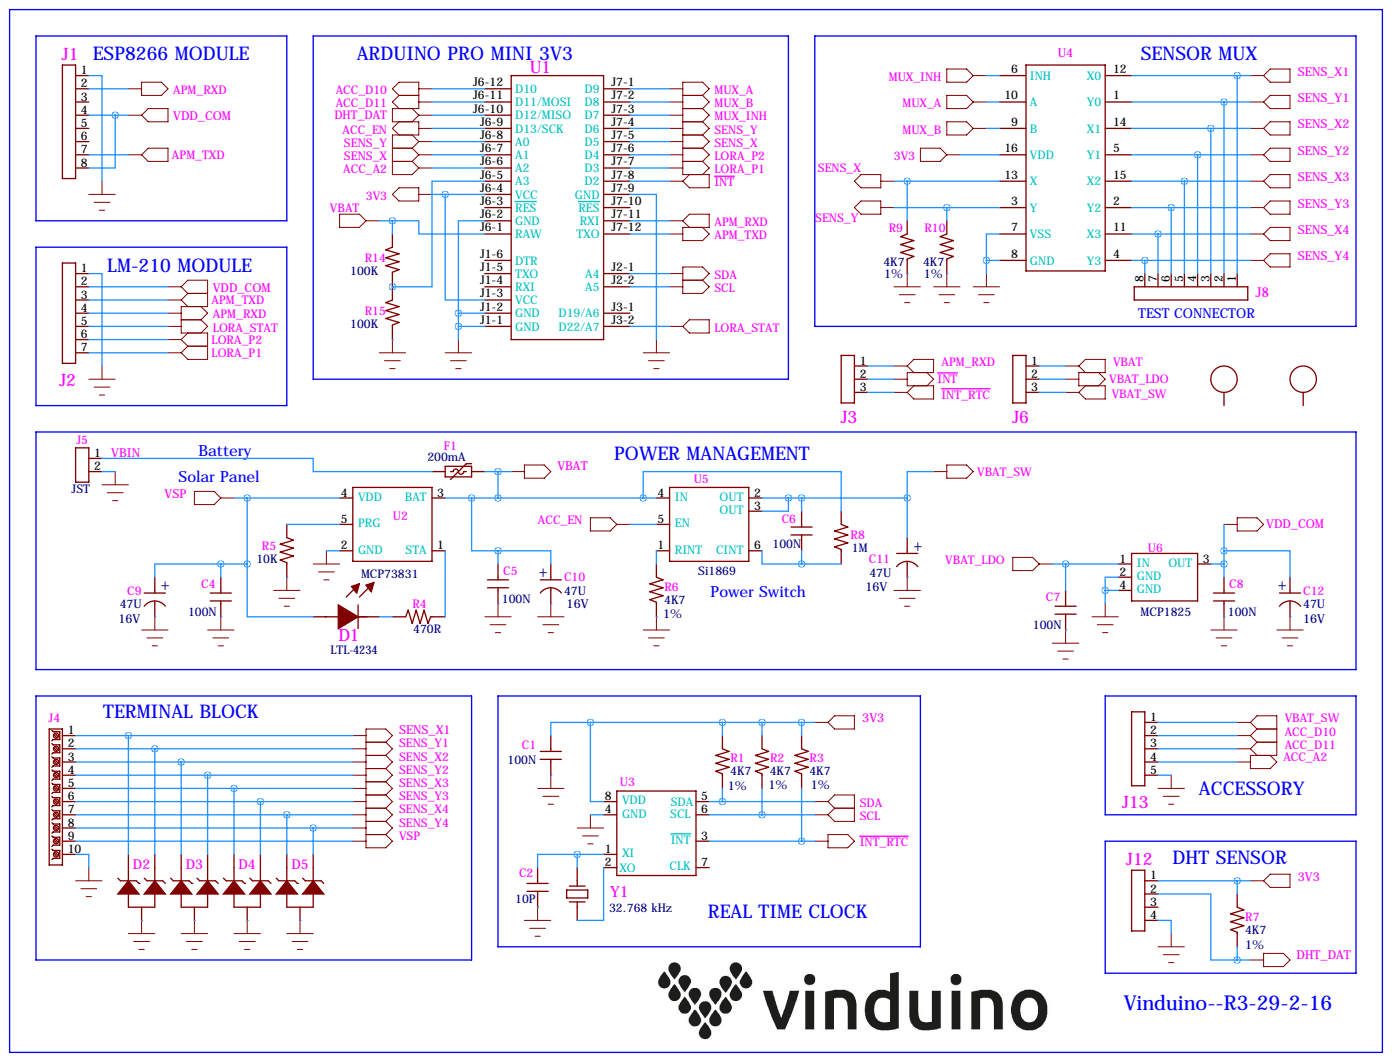
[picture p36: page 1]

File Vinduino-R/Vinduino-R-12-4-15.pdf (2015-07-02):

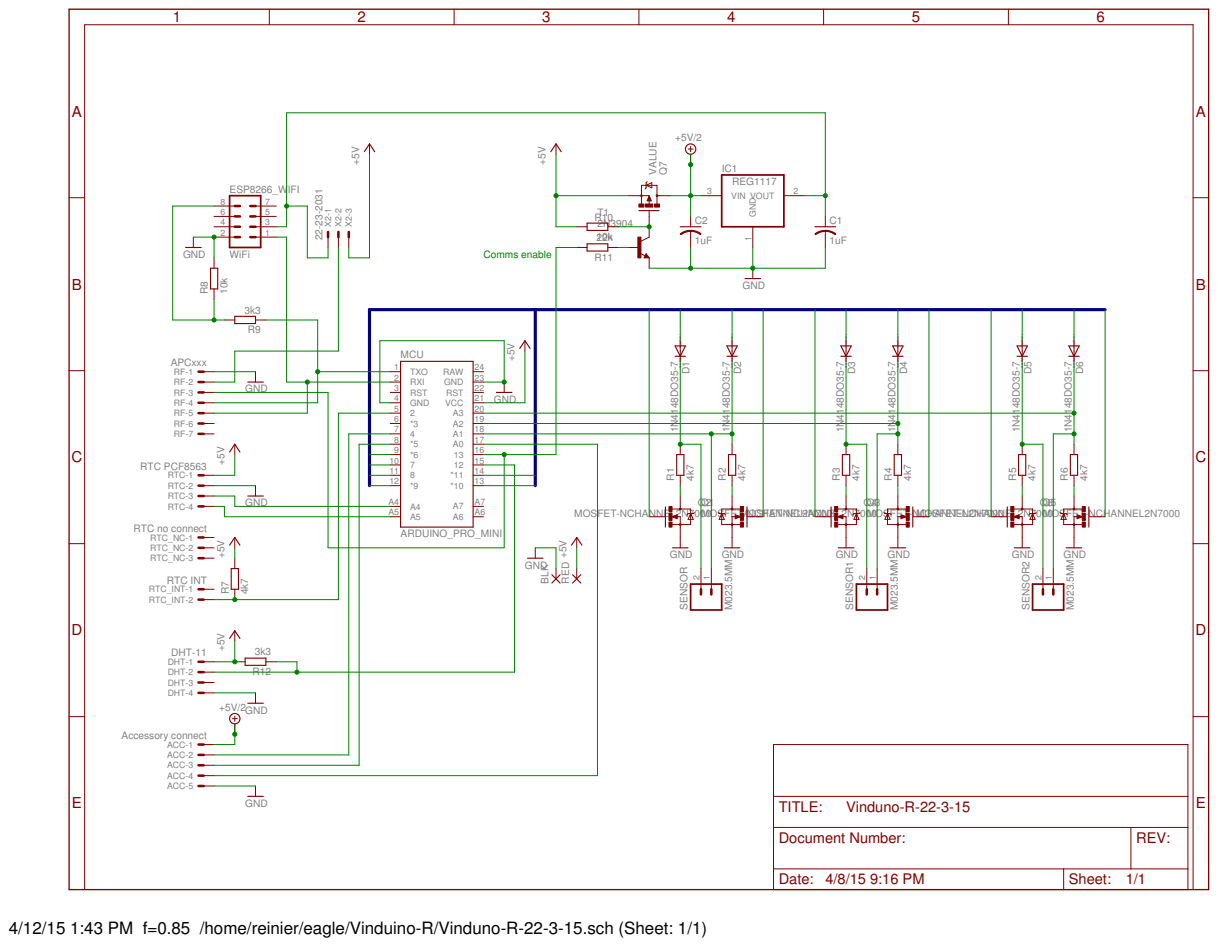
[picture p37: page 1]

APCxxx

6 7
10 | | 15
11 | | 14
12 | | 13

RTC no connect RTC INT
RTC_NC-1 RTC_NC-2 RTC_NC-3 RTC_INT-1 RTC_INT-2

ACC-1 ACC-2 ACC-3 ACC-4 ACC-5

Document Number: | REV:

Date: 4/8/15 9:16 PM | Sheet: 1/1

4/12/15 1:43 PM f=0.85 /home/reinier/eagle/Vinduino-R/Vinduno-R-22-3-15.sch (Sheet: 1/1)

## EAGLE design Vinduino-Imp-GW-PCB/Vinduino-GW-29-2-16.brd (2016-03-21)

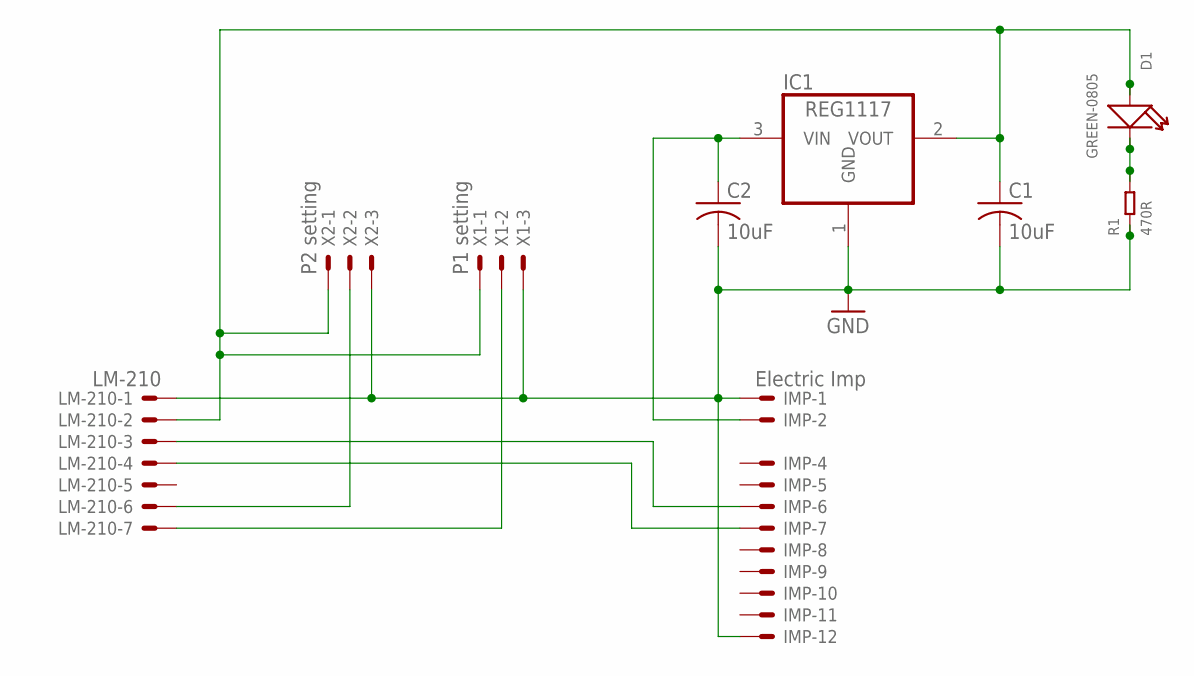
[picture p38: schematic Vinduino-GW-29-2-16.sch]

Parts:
C1, C2: 10uF; C025-030X050
D1: GREEN-0805; LED-0805
IC1: REG1117; SOT223
IMP: Electric Imp; 22-23-2121
LM-210: LM-210; 22-23-2071
R1: 470R; R0805
X1: P1 setting; 22-23-2031
X2: P2 setting; 22-23-2031

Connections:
GND: C1.2, C2.2, IC1.1 (GND), IMP.1, IMP.12, LM-210.1, R1.1, X1.3, X2.3
unnamed: C2.1, IC1.3 (VIN), IMP.2
unnamed: LM-210.6, X2.2
unnamed: LM-210.7, X1.2
unnamed: IMP.6, LM-210.3
unnamed: IMP.7, LM-210.4
unnamed: D1.-, R1.2
unnamed: C1.1, D1.+, IC1.2 (VOUT), LM-210.2, X1.1, X2.1

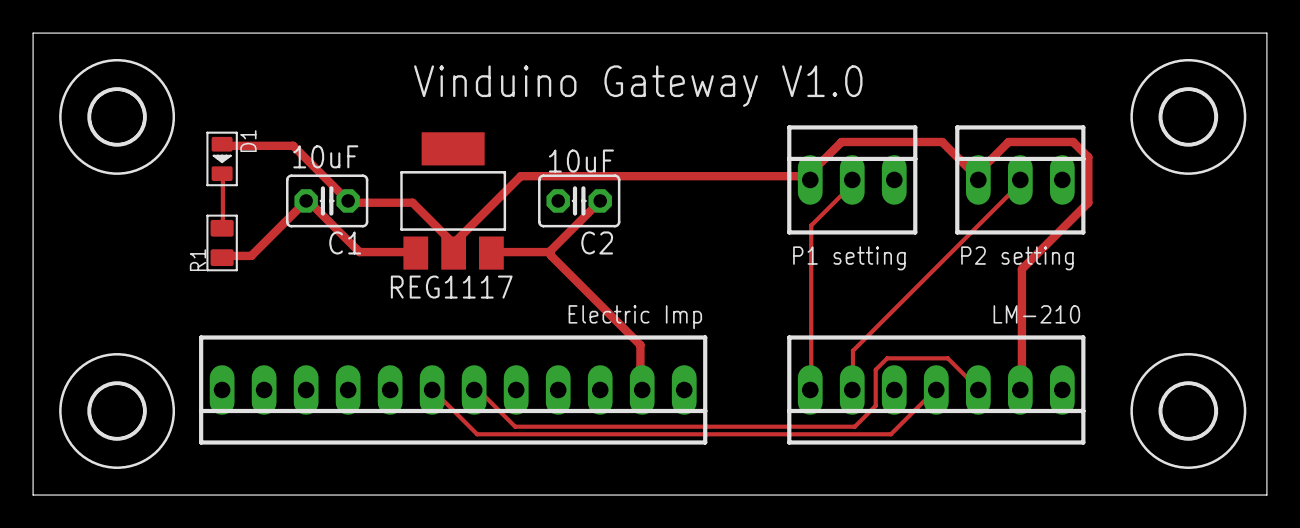
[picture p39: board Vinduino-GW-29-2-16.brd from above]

Board: 2 copper layers, 74.6 x 27.9 mm, 13 parts (0 on the bottom side), 8 nets.

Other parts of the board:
U$1, U$2, U$3, U$4: 3,2

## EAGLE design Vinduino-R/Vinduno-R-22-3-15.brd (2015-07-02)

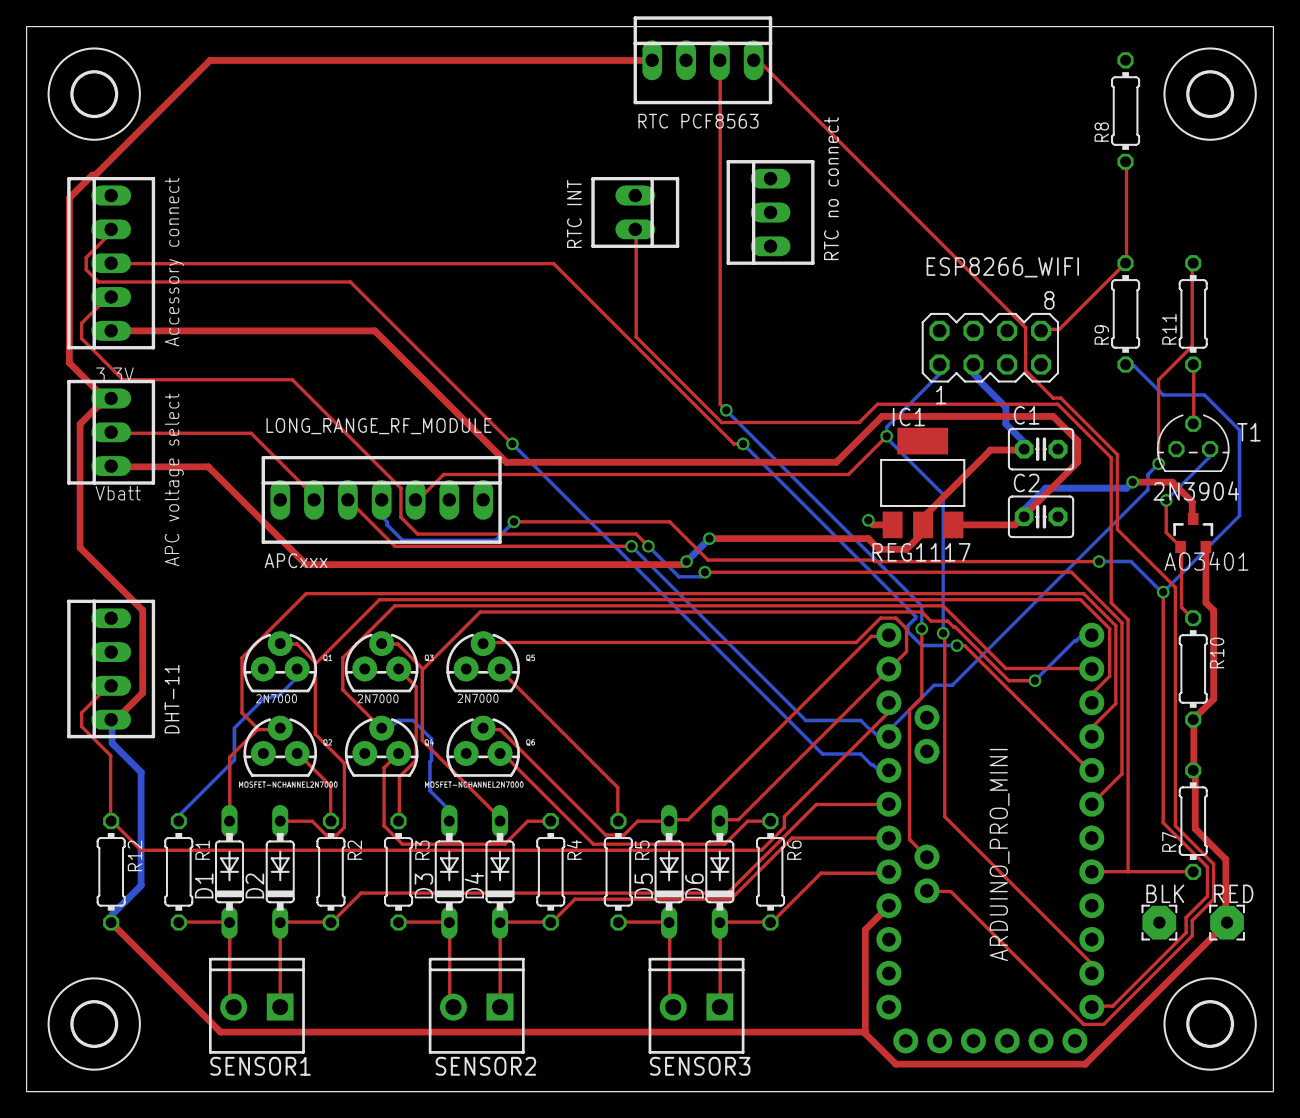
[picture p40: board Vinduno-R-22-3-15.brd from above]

Board: 2 copper layers, 93.7 x 80.0 mm, 47 parts (0 on the bottom side), 36 nets.

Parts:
ACC: Accessory connect; 22-23-2051
BLK: 2,54/0,9
C1, C2: 1uF; C025-030X050
D1, D2, D3, D4, D5, D6: 1N4148DO35-7; DO35-7
DHT: DHT-11; 22-23-2041
ESP8266_WIFI: WiFi; MA04-2
IC1: REG1117; SOT223
LONG_RANGE_RF_MODULE: APCxxx; 22-23-2071
MCU: ARDUINO_PRO_MINI
Q1, Q3, Q5: 2N7000; TO-92
Q2, Q4, Q6: MOSFET-NCHANNEL2N7000; TO-92
Q7: AO3401; SOT23-3
R1, R2, R3, R4, R5, R6, R7: 4k7; 0204/7
R8, R10: 10k; 0204/7
R9, R12: 3k3; 0204/7
R11: 22k; 0204/7
RED: 2,54/0,9
RTC: RTC PCF8563; 22-23-2041
RTC_INT: RTC INT; 22-23-2021
RTC_NC: RTC no connect; 22-23-2031
SENSOR1: Sensor 1; SCREWTERMINAL-3.5MM-2
SENSOR2, SENSOR3: M023.5MM; SCREWTERMINAL-3.5MM-2
T1: 2N3904; TO92
U$1, U$2, U$3, U$4: 3,2
X2: 22-23-2031

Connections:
+5V: DHT.1, MCU.21, Q7.2, R7.2, R10.2, R12.2, RED.1, RTC.1, X2.3
+5V/2: ACC.1, C2.1, IC1.3, Q7.3
DIODE1: D1.A, MCU.9, Q2.2
DIODE2: D2.A, MCU.10, Q1.2
DIODE3: D3.A, MCU.11, Q4.2
DIODE4: D4.A, MCU.12, Q3.2
DIODE5: D5.A, MCU.13, Q6.2
DIODE6: D6.A, MCU.14, Q5.2
GND: ACC.5, BLK.1, C1.2, C2.2, DHT.4, ESP8266_WIFI.2, IC1.1, LONG_RANGE_RF_MODULE.1, MCU.4, MCU.23, Q1.1, Q2.1, Q3.1, Q4.1, Q5.1, Q6.1, R8.2, RTC.2, T1.3
unnamed: D1.C, R1.2, SENSOR1.2
unnamed: D2.C, MCU.18, R2.2, SENSOR1.1
unnamed: D3.C, R3.2, SENSOR2.2
unnamed: D4.C, MCU.19, R4.2, SENSOR2.1
unnamed: Q1.3, R1.1
unnamed: D5.C, R5.2, SENSOR3.2
unnamed: D6.C, MCU.20, R6.2, SENSOR3.1
unnamed: ACC.4, MCU.17
unnamed: MCU.A4, RTC.3
unnamed: LONG_RANGE_RF_MODULE.3, MCU.16, R11.2
unnamed: LONG_RANGE_RF_MODULE.4, MCU.1, R9.1
unnamed: ESP8266_WIFI.1, LONG_RANGE_RF_MODULE.5, MCU.2
unnamed: MCU.A5, RTC.4
unnamed: Q2.3, R2.1
unnamed: Q3.3, R3.1
unnamed: Q4.3, R4.1
unnamed: Q5.3, R5.1
unnamed: Q6.3, R6.1
unnamed: ESP8266_WIFI.8, R8.1, R9.2
unnamed: DHT.2, MCU.15, R12.1
unnamed: ACC.3, MCU.8
unnamed: Q7.1, R10.1, T1.1
unnamed: R11.1, T1.2
unnamed: MCU.5, R7.1, RTC_INT.2
unnamed: ACC.2, MCU.7
unnamed: C1.1, ESP8266_WIFI.3, IC1.2, X2.1
unnamed: LONG_RANGE_RF_MODULE.2, X2.2

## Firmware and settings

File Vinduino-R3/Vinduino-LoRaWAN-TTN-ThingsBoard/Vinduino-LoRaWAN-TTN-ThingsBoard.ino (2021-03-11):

// Remote soil moisture 4-sensor node based on Vinduino R3
// Using LM-513H1 LoRa module, PCF8563 RTC,
// sensor 2,3: Watermark sensor @ 65F
// Date February, 2020
// Reinier van der Lee, www.vinduino.com

#include <Wire.h>                 // I2C communication to RTC
#include "LowPower.h"             // Needed for sleep mode, developed by "Rocketscream"
#include <math.h>                 // Conversion equation from resistance to %
#include <dht.h>                  // Rob Tillaart's library

//set up temp sensor
dht DHT;
#define DHT22_PIN 12



#define PCF8563address 0x51       // Format data for RTC
byte timercontrol, timervalue;    // for interrupt timer

//Use pin 2 for wake up from sleep mode interrupt
const int wakeUpPin = 2;

typedef struct {        // Structure to be used in percentage and resistance values matrix to be filtered (have to be in pairs)
  int moisture;
  int resistance;
} values;

// Setting up format for reading 4 soil sensors
#define NUM_READS 11   // Number of sensor reads for filtering

const long knownResistor = 4750;  // Value of R9 and R10 in Ohms, = reference for sensor

unsigned long supplyVoltage;      // Measured supply voltage
unsigned long sensorVoltage;      // Measured sensor voltage
int zeroCalibration = 95;        // calibrate sensor resistace to zero when input is short circuited
                                  // basically this is compensating for the mux switch resistance

values valueOf[NUM_READS];        // Calculated  resistances to be averaged
long buffer[NUM_READS];
int index2;
int i;                            // Simple index variable
int j=0;                          // Simple index variable

int tension1;
int tension2;
int tension3;
int tension4;

int Vsys;
int temp;
int humidity;

boolean joinAccept = false; 

String inputString = "";         // a String to hold incoming data
boolean stringComplete = false;  // whether the string is complete

int n =10;


void setup() {
  
  // initialize serial communications at 57600 bps:
  Serial.begin(57600);            // initialize LoRa module communications
  Wire.begin();                   // initialize I2C communications
  
  // reserve 200 bytes for the inputString:
  inputString.reserve(200);
  
  // Configure wake up pin as input.
  // This will consume few uA of current.
  pinMode(wakeUpPin, INPUT);  

  // setting up the LM-210 LoRa module control pins:
  pinMode(3, OUTPUT); // module P1 pin
  pinMode(4, OUTPUT); // module P2 pin

  // P1=0 and P2=0 : module active mode (Mode 1)
  // P1=0 and P2=1 : module wake-up mode (Mode 2)
  // P1=1 and P2=0 : module power saving mode (Mode 3)
  // P1=1 and P2=1 : module set-up mode (Mode 4)
  
// setting up the sensor interface
  // initialize digital pins D5, D6 as an high impedance input.
  // Pin 5,6 are for driving the soil moisture sensor
  pinMode(5, INPUT);    
  pinMode(6, INPUT); 
  // Pin 7 is for enabling Mux switches
  pinMode(7, OUTPUT); 
  // Pin 8,9 are for selecting sensor 1-4
  pinMode(8, OUTPUT);  // Mux input A
  pinMode(9, OUTPUT);  // Mux input B 
 
  // Pin 13 is used as WiFi radio and aux power enable, as well as activity indicator
  pinMode(13, OUTPUT);  


  digitalWrite(3, LOW); // module P1 pin
  digitalWrite(4, LOW); // module P2 pin

   Serial.println (255, HEX); // wake-up LM-130 from sleep mode

  for (i = 0; i < n; i++) 
  {serialEvent();
  Serial.println (i);
  if (joinAccept == 1) i=n;
  delay (1000);
  }
  Serial.print ("joinAccept = ");
  Serial.println (joinAccept);
  if (joinAccept == 0) { loraconfig(); }
  if (joinAccept) { Serial.println ("no lora config needed");}

  soilsensors(); 
}


void loop() 
{
 digitalWrite(13, LOW); //  LED off;
 
  for (i = 0; i < n; i++) 
  {serialEvent();
  Serial.println (i);
  delay (300);
  }

   Serial.println("AAT1 SLEEP"); delay (200);

   settimerPCF8563();      // set the timer delay and alarm

   // Allow wake up pin to trigger interrupt on low.
   attachInterrupt(0, wakeUp, LOW);
    
   // Enter power down state with ADC and BOD module disabled.
   // Wake up when wake up pin is low.
  LowPower.powerDown(SLEEP_FOREVER, ADC_OFF, BOD_OFF);     

   // Disable external pin interrupt on wake up pin.
  detachInterrupt(0); 
 Serial.println(255,HEX);

  delay (100);

  soilsensors(); 

    

delay (1000);

}

void soilsensors(){
  
// Select sensor 1, and enable MUX
  digitalWrite(8, LOW); 
  digitalWrite(9, LOW); 
  digitalWrite(7, LOW); 
  measureSensor();
 // double tension1 = average();  //use this line to display uncalibrated sensor resistance
 unsigned long read1 = average();
  if (read1 >35000){tension1=255;}
  if (read1 >1000 && read1 <=35000){tension1=-0.000000000003*pow(read1,3)+0.0000002*pow(read1,2)+(0.0037*read1)+6.73;}
  if (read1<=1000){tension1=(read1-400)/60;}
  if (read1<400){tension1=0;}

// Select sensor 2, and enable MUX
  digitalWrite(8, LOW); 
  digitalWrite(9, HIGH); 
  digitalWrite(7, LOW); 
  measureSensor();
  //double tension2 = average();  //use this line to display uncalibrated sensor resistance
  unsigned long read2 = average();
  if (read2 >35000){tension2=255;}
  if (read2 >1000 && read2 <=35000){tension2=-0.000000000003*pow(read2,3)+0.0000002*pow(read2,2)+(0.0037*read2)+6.73;}
  if (read2<=1000){tension2=(read2-400)/60;}
  if (read2<400){tension2=0;}

    // Select sensor 3, and enable MUX
  digitalWrite(8, HIGH); 
  digitalWrite(9, LOW); 
  digitalWrite(7, LOW); 
  measureSensor();
  //double tension3 = average();  //use this line to display uncalibrated sensor resistance
  unsigned long read3 = average();
  if (read3 >35000){tension3=255;}
  if (read3 >1000 && read3 <=35000){tension3=-0.000000000003*pow(read3,3)+0.0000002*pow(read3,2)+(0.0037*read3)+6.73;}
  if (read3<=1000){tension3=(read3-400)/60;}
  if (read3<400){tension3=0;}

  // Select sensor 4, and enable MUX
  digitalWrite(8, HIGH); 
  digitalWrite(9, HIGH); 
  digitalWrite(7, LOW); 
  measureSensor();
  //double tension4 = average();  //use this line to display uncalibrated sensor resistance
  unsigned long read4 = average();
  if (read4 >35000){tension4=255;}
  if (read4 >1000 && read4 <=35000){tension4=-0.000000000003*pow(read4,3)+0.0000002*pow(read4,2)+(0.0037*read4)+6.73;}
  if (read4<=1000){tension4=(read4-400)/60;}
  if (read4<400){tension4=0;}

  int Vsys = analogRead(3)*0.00647*50;   // read the battery voltage


 //digitalWrite(4, LOW); // module P2 pin
 //digitalWrite(3, LOW); // module P1 pin
 digitalWrite(13, HIGH); // LED ON
   delay (50);

  Vsys = analogRead(3)*0.00647*50;   // read the battery voltage
  delay (10);

  //Read DHT-22 sensor
  int chk = DHT.read22(DHT22_PIN);      // temperature sensor data

  temp = DHT.temperature;
  humidity = DHT.humidity;
  temp = temp +100 ; //use this line when sensor installed
  //temp = 100; humidity = 0; //use this line when sensor NOT installed

  TxData();
}

  void TxData(){
  Serial.print("AAT2 Tx=2,uncnf,");
  
  if (Vsys<16) //add leading zero
  {Serial.print(0, HEX);}
  if (Vsys>255) //handle overflow
  {Vsys = 255;}
  Serial.print(Vsys, HEX); 
  
  if (temp<16) //add leading zero fix
  {Serial.print(0, HEX);}
  if (temp>255) //handle overflow
  {temp = 255;}
  Serial.print(temp, HEX); 

  if (humidity<16) //add leading zero fix
  {Serial.print(0, HEX);}
  if (humidity>255) //handle overflow
  {humidity = 255;}
  Serial.print(humidity, HEX);

  
  if (tension1<16) //add leading zero fix
  {Serial.print(0, HEX);}
  if (tension1>255) //handle overflow
  {tension1 = 255;}
  Serial.print(tension1,HEX);  

  
  if (tension2<16) //add leading zero fix
  {Serial.print(0, HEX);}
  if (tension2>255) //handle overflow
  {tension2 = 255;}
  Serial.print(tension2,HEX); 

  
  if (tension3<16) //add leading zero fix
  {Serial.print(0, HEX);}
  if (tension3>255) //handle overflow
  {tension3 = 255;}
  Serial.print(tension3,HEX); 

  
  if (tension4<16) //add leading zero fix
  {Serial.print(0, HEX);}
  if (tension4>255) //handle overflow
  {tension4 = 255;}
  Serial.println(tension4,HEX);

  delay (500);
  

  digitalWrite(13, LOW); //  LED off

  return;
}

void measureSensor()
{

  for (i=0; i<NUM_READS; i++) 
      {
  
    pinMode(5, OUTPUT); 
    digitalWrite(5, LOW);  
    digitalWrite(5, HIGH); 
    delayMicroseconds(250);
    sensorVoltage = analogRead(0);   // read the sensor voltage
    supplyVoltage = analogRead(1);   // read the supply voltage
    digitalWrite(5, LOW); 
    pinMode(5, INPUT);
    long resistance = (knownResistor * (supplyVoltage - sensorVoltage ) / sensorVoltage)-zeroCalibration ;
    
   addReading(resistance);
   delayMicroseconds(250);

    pinMode(6, OUTPUT); 
    digitalWrite(6, LOW);  
    digitalWrite(6, HIGH); 
    delayMicroseconds(250);
    sensorVoltage = analogRead(1);   // read the sensor voltage
    supplyVoltage = analogRead(0);   // read the supply voltage
    digitalWrite(6, LOW); 
    pinMode(6, INPUT);
    resistance = (knownResistor * (supplyVoltage - sensorVoltage ) / sensorVoltage)-zeroCalibration ;
    
   addReading(resistance);
   delay(100);

      } 
}


// Averaging algorithm
void addReading(long resistance){
  buffer[index2] = resistance;
  index2++;
  if (index2 >= NUM_READS) index2 = 0;
}
  long average(){
  long sum = 0;
  for (int i = 0; i < NUM_READS; i++){
    sum += buffer[i];
  }
  return (long)(sum / NUM_READS);
}


void wakeUp()
{
    // Just a handler for the pin interrupt.
}

// RTC routines below

void PCF8563alarmOff()
// turns off alarm enable bits and wipes alarm registers. 
{
  byte test;
  // first retrieve the value of control register 2
  Wire.beginTransmission(PCF8563address);
  Wire.write(0x01);
  Wire.endTransmission();
  Wire.requestFrom(PCF8563address, 1);
  test = Wire.read();

  // set bit 2 "alarm flag" to 0
  test = test - B00000100;

  // now write new control register 2  
  Wire.beginTransmission(PCF8563address);
  Wire.write(0x01);
  Wire.write(test);
  Wire.endTransmission();
}


void checkPCF8563alarm()    // checks if the alarm has been activated
{
  byte test;
  // get the contents from control register #2 and place in byte test;
  Wire.beginTransmission(PCF8563address);
  Wire.write(0x01);
  Wire.endTransmission();
  Wire.requestFrom(PCF8563address, 1);
  test = Wire.read();
  test = test & B00000100 ;// read the timer alarm flag bit
  
  if (test == B00000100)// alarm on?
  {digitalWrite(13, HIGH);   // turn pin 13 and Radio module on (HIGH is the voltage level)
   delay(50);
   PCF8563alarmOff(); }      // turn off the alarm
  
}

void settimerPCF8563()
// this sets the timer from the PCF8563
{
Wire.beginTransmission(PCF8563address);
Wire.write(0x0E); // move pointer to timer control address

Wire.write(0x83); // sends 0x83 Hex 010000011 (binary)
// (0x82 = enable timer,timer clock set to 1 second)
// (0x83 = enable timer,timer clock set to 1 minute)
Wire.endTransmission();
 
Wire.beginTransmission(PCF8563address);
Wire.write(0x0F); // move pointer to timer value address
Wire.write(0x0F); // sends delay time value (0F =15 minutes, 1E = 0.5 hour, 3C = 1 hour)
Wire.endTransmission();

// optional - turns on INT_ pin when timer activated
// will turn off once you run void PCF8563alarmOff()
Wire.beginTransmission(PCF8563address);
Wire.write(0x01); // select control status_register
Wire.write(B00000001); // set Timer INT enable bit
Wire.endTransmission();
}

void loraconfig()
// this initializes the LM-513 LoRa module to TTN LoRaWAN OTAA
{
  
  //Serial.println("AAT1 Reset"); delay (5000); //assume successful join to TTN network
  // set join mode = OTAA, ADR=0, DutyCycle=on)
  Serial.println("AAT2 JoinMode=1"); delay (50);
  Serial.println("AAT2 ADR=0"); delay (50);
  Serial.println("AAT2 DutyCycle=1"); delay (50);

  
  //Set 8 channel TX frequencies for TTN USA, for EU version do not set frequencies
  Serial.println("AAT2 Tx_Channel=0,903900000,30,1,0"); delay (50);
  Serial.println("AAT2 Tx_Channel=1,904100000,30,1,0"); delay (50);
  Serial.println("AAT2 Tx_Channel=2,904300000,30,1,0"); delay (50);
  Serial.println("AAT2 Tx_Channel=3,904500000,30,1,0"); delay (50);
  Serial.println("AAT2 Tx_Channel=4,904700000,30,1,0"); delay (50);
  Serial.println("AAT2 Tx_Channel=5,904900000,30,1,0"); delay (50); 
  Serial.println("AAT2 Tx_Channel=6,905100000,30,1,0"); delay (50);
  Serial.println("AAT2 Tx_Channel=7,905300000,30,1,0"); delay (50);


  // set AppEui & AppKey
  Serial.println("AAT2 DevEui=xxxxxxxxxxxxxx"); delay (50); // get the DevEUI from The Things Network console
  Serial.println("AAT2 AppEui=xxxxxxxxxxxxxx"); delay (50); // get the AppEUI from The Things Network console

  Serial.println("AAT2 AppKey=xxxxxxxxxxxxxx"); delay (50); // get the Appkey from The Things Network console

  
  Serial.println("AAT1 Save"); delay (5000);

  // save and reset;
  Serial.println("AAT1 Reset"); delay (1000); //assume successful join to TTN network

}

/*
  SerialEvent occurs whenever a new data comes in the hardware serial RX. This
  routine is run between each time loop() runs, so using delay inside loop can
  delay response. Multiple bytes of data may be available.
*/
void serialEvent() {
  while (Serial.available()) {
    // get the new byte:
    char inChar = (char)Serial.read();
    // add it to the inputString:
    inputString += inChar;
    // if the incoming character is a newline, set a flag so the main loop can
    // do something about it:
    if (inChar == '\n') {
      stringComplete = true;
      SerialParse ();
    }
  }
}

void SerialParse () {
  // print the string when a newline arrives:
  if (stringComplete) {
    Serial.println(inputString);
    if(inputString.indexOf("JOIN_NOT_ACCEPT") >= 0) {Serial.println("JOIN_NOT_ACCEPT action");signal_Led(1);};
    if(inputString.indexOf("JOIN_ACCEPT") >= 0) {Serial.println("JOIN_ACCEPT action"); joinAccept = true; signal_Led(2);};
    if(inputString.indexOf("Tx_ok") >= 0) {Serial.println("Tx_ok action"); signal_Led(3); i=10;};
    if(inputString.indexOf("Tx_no_free_ch") >= 0) {Serial.println("Tx_no_free_ch action"); signal_Led(4);};
    if(inputString.indexOf("Tx_not_joined") >= 0) {Serial.println("Tx_not_joined action"); signal_Led(5);};
    if(inputString.indexOf("Tx_noACK") >= 0) {Serial.println("Tx_noACK action"); signal_Led(6);};
    if(inputString.indexOf("invalid_param") >= 0) {Serial.println("invalid_param action"); signal_Led(7);};
    
    //INPUT DATA WAS PARSED, SO WE GET BACK TO INITIAL STATE.
    inputString = "";
    stringComplete = false;
}}

void signal_Led(int n) {

  for (i = 0; i < n; i++) 
  {
    digitalWrite(13, HIGH);
    delay (500);
    digitalWrite(13, LOW); //  LED off;
    delay (500);
  }
}

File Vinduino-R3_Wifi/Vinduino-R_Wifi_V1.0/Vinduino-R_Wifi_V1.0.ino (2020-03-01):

// Remote soil moisture 3-sensor node based on Vinduino-H V3
// Using ESP2866 Wifi module and PCF8563 RTC
// Using latest DHT libaray, allowing use of DHT11 or DHT 22
// Added galvanic voltage bias compensation
// Date May 24, 2015
// Copyright (C), 2015, Reinier van der Lee, 
// www.vanderleevineyard.com

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
#include "LowPower.h"   // Needed for sleep mode
#include <Wire.h>       // I2C communication to RTC
#include <math.h>       // Conversion equation from resistance to %
#include <dht.h>

// Wifi connection data
#define SSID "insert wifi network name here"
#define PASS "insert your network password here"
#define IP "184.106.153.149" // thingspeak.com
String GET = "GET /update?key="VSBQNUSZ0RCICFRK" &1=";

//set up temp sensor
dht DHT;
#define DHT11_PIN 12

#define PCF8563address 0x51

// Use pin 2 as wake up pin
const int wakeUpPin = 2;

// set up variables for battery voltage measurement
int analoginput = 0; // our analog pin
int analogamount = 0; // stores incoming value
float voltage =0; // used to store voltage value

// Format data for RTC
//byte second, minute, hour, dayOfWeek, dayOfMonth, month, year;
//byte alarmMinute, alarmHour, alarmDay, alarmDayOfWeek;
byte timercontrol, timervalue; //  for interrupt timer
//String days[] = {"Sunday", "Monday", "Tuesday", "Wednesday", "Thursday", "Friday", "Saturday" };

//byte bcdToDec(byte value)
//{
//  return ((value / 16) * 10 + value % 16);
//}

//byte decToBcd(byte value){
//  return (value / 10 * 16 + value % 10);
//}

// Setting up format for reading 3 soil sensors
#define NUM_READS 11    // Number of sensor reads for filtering

typedef struct {        // Structure to be used in percentage and resistance values matrix to be filtered (have to be in pairs)
  int moisture;
  long resistance;
} values;


const long knownResistor = 4700;  // Constant value of known resistor in Ohms

int supplyVoltage;                // Measured supply voltage
int sensorVoltage;                // Measured sensor voltage

values valueOf[NUM_READS];        // Calculated  resistances to be averaged
long buffer[NUM_READS];
int index;

int i;                            // Simple index variable


long readVcc() { 
long result;                       // Read 1.1V reference against AVcc 
ADMUX = _BV(REFS0) | _BV(MUX3) | _BV(MUX2) | _BV(MUX1); 
delay(2); // Wait for Vref to settle 
ADCSRA |= _BV(ADSC); // Convert 
while (bit_is_set(ADCSRA,ADSC)); 
result = ADCL; 
result |= ADCH<<8; 
result = (1125300L / result); // Back-calculate AVcc in mV 
return result; 
}


void setup() {
  // initialize serial communications at 9600 bps:
  Serial.begin(9600); 
  
    // initialize I2C communications
  Wire.begin();
  
  // Configure wake up pin as input.
  // This will consume few uA of current.
  pinMode(wakeUpPin, INPUT);   

  // initialize the digital pins as an output.
  // Pin 6,7 is for sensor 1
  pinMode(6, OUTPUT);    
  pinMode(7, OUTPUT); 
  // Pin 8,9 is for sensor 2
  pinMode(8, OUTPUT);    
  pinMode(9, OUTPUT);  
  // Pin 10,11 is for sensor 3
  pinMode(10, OUTPUT);    
  pinMode(11, OUTPUT);
  
  // Pin 13 is radio enable
 pinMode(13, OUTPUT);      
  
  // set the timer delay and alarm
  settimerPCF8563();
  
}

void loop() {
  
   
 // Allow wake up pin to trigger interrupt on low.
 attachInterrupt(0, wakeUp, LOW);
    
   // Enter power down state with ADC and BOD module disabled.
   // Wake up when wake up pin is low.
  LowPower.powerDown(SLEEP_FOREVER, ADC_OFF, BOD_OFF); 
    
   // Disable external pin interrupt on wake up pin.
  detachInterrupt(0); 
   

   // If alarm, make pin 13 (radio enable) high
  checkPCF8563alarm();
   delay(500);
   
   //Restart radio module
      Serial.println("AT+RST");
  delay(5000);
  if(Serial.find("ready")){
    connectWiFi();
  }
 // read sensor 1-3, filter, and calculate resistance value
 // Noise filter: median filter
 
measure(1,6,7,1);
long read1 = average();
measure(1,7,6,0);
long read2= average();
long sensor1 = (read1 + read2)/2;

delay (100);


measure(2,8,9,2);
long read3 = average();
measure(2,9,8,6);
long read4= average();
long sensor2 = (read3 + read4)/2;

delay (100);

measure(3,10,11,3);
long read5 = average();
measure(3,11,10,7);
long read6= average();
long sensor3 = (read5 + read6)/2;


 // measure and print battery voltage
 float Vcc = (readVcc());
 Vcc =Vcc/1000;
 //Serial.print("Battery voltage: ");
 //Serial.print( Vcc,2);
 //Serial.println (" V");
 //Serial.println();


  int temp;
  int humidity;
  int chk = DHT.read11(DHT11_PIN);    // READ DATA

    temp = DHT.temperature,1;
    humidity = DHT.humidity,1;
    
   // convert data to string
  char buf[16];
  String strTemp = dtostrf(temp, 4, 1, buf);
  
  char hum[16];
  String strHumidity = dtostrf(humidity, 4, 1, buf);
  
  char sn1[16];
  String strsensor1 = dtostrf(sensor1, 4, 1, buf);
  
  char sn2[16];
  String strsensor2 = dtostrf(sensor2, 4, 1, buf);
  
  char sn3[16];
  String strsensor3 = dtostrf(sensor3, 4, 1, buf);
  
  char Vbatt[16];
  String strVcc = dtostrf(Vcc, 4, 1, buf);
  
  updateTemp(strTemp, strHumidity, strsensor1, strsensor2, strsensor3, strVcc );
  

}

void measure (int sensor, int phase_b, int phase_a, int analog_input)
{
 
  // read sensor, filter, and calculate resistance value
  // Noise filter: median filter

  for (i=0; i<NUM_READS; i++) {

    // Read 1 pair of voltage values
    digitalWrite(phase_a, HIGH);                 // set the voltage supply on
    delayMicroseconds(25);
    supplyVoltage = analogRead(analog_input);   // read the supply voltage
    delayMicroseconds(25);
    digitalWrite(phase_a, LOW);                  // set the voltage supply off 
    delay(1);
     
    digitalWrite(phase_b, HIGH);                 // set the voltage supply on
    delayMicroseconds(25);
    sensorVoltage = analogRead(analog_input);   // read the sensor voltage
    delayMicroseconds(25);
    digitalWrite(phase_b, LOW);                  // set the voltage supply off 

    // Calculate resistance
    // the 0.5 add-term is used to round to the nearest integer
    // Tip: no need to transform 0-1023 voltage value to 0-5 range, due to following fraction
    long resistance = (knownResistor * (supplyVoltage - sensorVoltage ) / sensorVoltage) ;
    
    delay(1); 
    addReading(resistance);
    
   }
  }


// Averaging algorithm
void addReading(long resistance){
  buffer[index] = resistance;
  index++;
  if (index >= NUM_READS) index = 0;
}

long average(){
  long sum = 0;
  for (int i = 0; i < NUM_READS; i++){
    sum += buffer[i];
  }
  return (long)(sum / NUM_READS);
}


void wakeUp()
{
    // Just a handler for the pin interrupt.
}

// RTC routines below
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

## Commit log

2015-06-07 Create Vinduino-R_Wifi_V1.0
    Remote soil moisture 3-sensor node based on Vinduino-H V3
    Using ESP2866 Wifi module and PCF8563 RTC
    Using latest DHT libaray, allowing use of DHT11 or DHT 22
    Added galvanic voltage bias compensation
2015-06-07 Create Vinduino-R_sensor_test
    This sketch can be used to test the 3 sensor inputs, and can also be used to demonstrate bias errors caused by galvanic voltages generated by the sensors. This sketch does not work with ESP8266 installed, it provides serial output only.
    Arduino analog inputs A0, A6, and A7 need to be connected.
2015-06-07 Create water_pressure_logger.ino
    This project requires three main components: an Arduino Uno board, an Adafruit data logger shield, and a 200 PSI pressure transducer (Eyourlife Universal 200PSI Pressure Transducer Sender Solenoid fo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
    See for transducer also: http://www.vanderleevineyard.com/1/post/2015/03/vinduino-water-pressure-meter.html
2015-06-07 Create Irrigation_valve_control.ino
    Hunter Sprinkler ICV201GDC ICV irrigation control valves can optionally use a DC latching solenoid (Hunter Sprinkler 458200 DC Latching Solenoid) for operation with a battery operated operated (Hunte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
    The latching solenoid can easily be driven with an Arduino board and a low cost motor driver module like L9110S DC Stepper Motor Driver Module H Bridge, available on-line for less than $6.
    The module needs 2 digital control lines (Arduino pin 13: latching on, and pin 12: latching off) per solenoid. The L9110S is a dual motor driver, so 2 valves can be controlled by one single module.
    The solenoid needs 9V to operate, a small battery pr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
2015-06-07 Create water_pressure_meter.ino
    Here's code for a digital water pressure meter, based on the Arduino Pro Mini micro controller board, and the Vinduino-H PCB.
    The used pressure sensor is a $20 device, available on-line. It has a stainless steel housing and comes complete with a watertight connection cable. There are several ranges available. We purchased t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
    This sensor gives an output voltage between 0.5V and 4.5V that scales linearly with the measured pressure, 50 psi per volt.
    Hooking the sensor up to the Arduino board is easy. Only 3 wires are required: 5V supply (connect to Arduino Vcc pin), ground, and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
2015-07-02 Vinduino Eagle files
    [Vinduino-H V0.2.sch, Vinduno-R-22-3-15.brd, Vinduno-R-22-3-15.sch]
2015-10-06 Small change.
    Well done!!! Love the Gypsum Moisture sensor... :)
2016-03-21 Next generation Vinduino added
    Added option for LoRa long range networking and several improvements
    [Vinduino-GW-29-2-16.brd, Vinduino-GW-29-2-16.sch, Vinduno-R-22-3-15.brd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]
2016-05-02 BOM
    Components listing
    [Vinduino-R3 bill of materials.xls]
2016-07-30 Manual
    Vinduino R3 remote sensor station manual
    [Vinduino-R3 bill of materials.xls]
2016-08-04 User manual update
    Added sensor calibration chart
2016-09-11 Test program
    Test program that comes pre-installed on the Vinduino board. Serial
    data output of resistance values measured at the soil sensor inputs
    every 3 seconds
2016-09-11 Program connector
    LoRa module IO is 3.3V. Do not connect when programming the Arduino to
    avoid 5V on LoRa module IOlines.
2016-09-24 Create Gateway-device-code
    Vinduino LoRa LAN gateway code for the Electric Imp. Enter this in the right side editor window (device code).
    Originally developed by Luke Beno, changed for ThingSpeak support. Provided under the GNU General Public License
2017-02-04 Removed old ESP8266 code and replaced with version for R3
    [VR3-WiFi-sample_code.ino, Vinduino-R_Wifi_V1.0.ino]
2017-02-04 clean up, added WiFi code
    [Vinduino-GW-29-2-16.brd, Vinduino-GW-29-2-16.sch, Vinduino-H V0.2.sch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]
2017-03-08 Update March 2017
    [Vinduino-H V0.2.sch, Vinduino-R3 bill of materials.xls, Vinduno-R-22-3-15.brd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]
2017-08-06 Added conversions to Watermark Sensors
    Direct calculation to watermark kPa instead of the % moisture, as % moisture is dependant on soil type and less useful for varying conditions. All calculations taken directly from: https://www.kimber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
2018-03-10 Updates 3-10-18
    Updates and added support for FDR sensor
2020-03-01 Added bOM
    Vinduino R3 bill of materials
    [Vinduino R3 bill of materials.xls]
2020-06-20 Chirpstack + ham radio update
    Chirpstack database backup and ham radio CW Arduino keyer added
2021-02-27 If humidity sensor is not connected default to 0. Otherwise the default value is -999 which fails to convert to HEX nicely.
    [Vinduino-LoRaWAN-TTN-ThingsBoard.ino, Vinduino-LoRaWAN-TTN.ino]

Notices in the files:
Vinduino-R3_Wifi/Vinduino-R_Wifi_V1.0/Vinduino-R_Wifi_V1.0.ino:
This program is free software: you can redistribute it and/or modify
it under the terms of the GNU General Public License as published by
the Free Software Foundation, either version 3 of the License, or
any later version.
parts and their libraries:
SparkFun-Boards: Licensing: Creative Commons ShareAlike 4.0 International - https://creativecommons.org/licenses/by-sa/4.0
